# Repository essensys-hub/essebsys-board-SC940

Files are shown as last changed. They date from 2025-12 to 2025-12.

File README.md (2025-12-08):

# SC940 Board Project

Welcome to the **Essensys SC940 Board** project repository. This project contains the hardware design and firmware source code for the SC940 board.

## Documentation

Full documentation for this project is available and can be built using MkDocs.
It covers:
- **Hardware**: Schematics, PCB layouts, and manufacturing files.
- **Firmware**: Source code and programming guides.

### Viewing Documentation Locally
To view the documentation locally:

1. Install MkDocs and the Material theme:
   ```bash
   pip install mkdocs-material
   ```
2. Run the documentation server:
   ```bash
   mkdocs serve
   ```
3. Open your browser to `http://127.0.0.1:8000`.

## Project Structure

- `SC940D/`: Electronic design files (Altium Designer), including Schematics and PCB.
- `SC940D/Prog/`: Firmware source code and hex files.
- `docs/`: Documentation source files.
- `mkdocs.yml`: MkDocs configuration.

## License

This project is licensed under the MIT License - see the [LICENSE](LICENSE) file for details.

Copyright (c) 2025 Essensys

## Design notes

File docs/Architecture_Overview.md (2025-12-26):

# Vue d'ensemble de l'Architecture : Boîtier Essensys SC940D

## 1. Description Générale
Le **SC940D** est une unité centrale de contrôle ("Boîtier Pièce de Vie") conçue pour l'automatisation des bâtiments. Il agit comme une passerelle et un contrôleur d'actionneurs, gérant l'éclairage, les volets roulants et d'autres charges 230V via des relais embarqués.

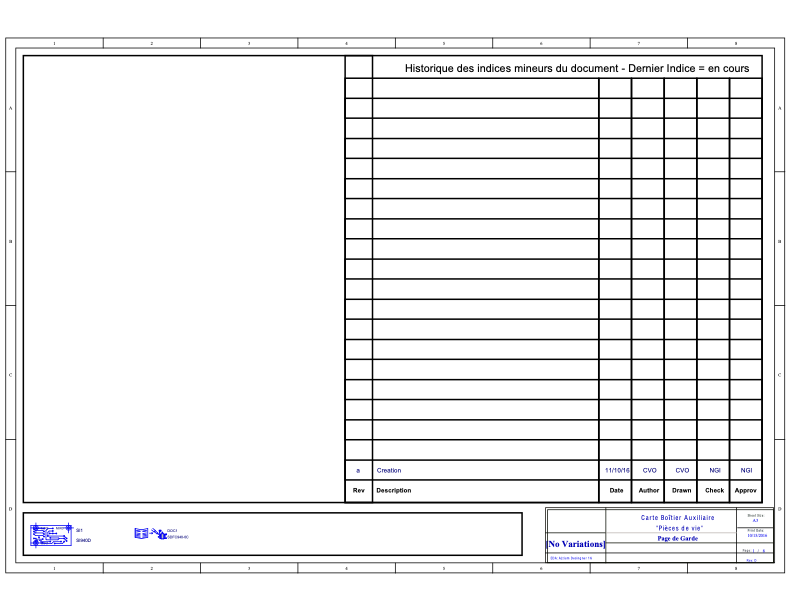
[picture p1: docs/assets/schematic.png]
SC940D Schematic

> [Télécharger le Schéma Complet (PDF)](assets/SC940D_Schematic.pdf)

## 2. Cœur de Traitement & Communication
### Microcontrôleur (MCU)
-   **Composant**: Microchip **PIC16F946** (MCU CMOS 8-bit).
-   **Boîtier**: 64-pin TQFP (`PIC16F946-I/PT`).
-   **Rôle**: Gère la logique locale, les signaux de contrôle des relais, et s'interface avec le module de communication. 
    -   *Note*: Le PIC16F946 possède un pilote LCD, mais il a probablement été choisi ici pour son grand nombre d'entrées/sorties (64 broches) ou pour des raisons d'historique composant.

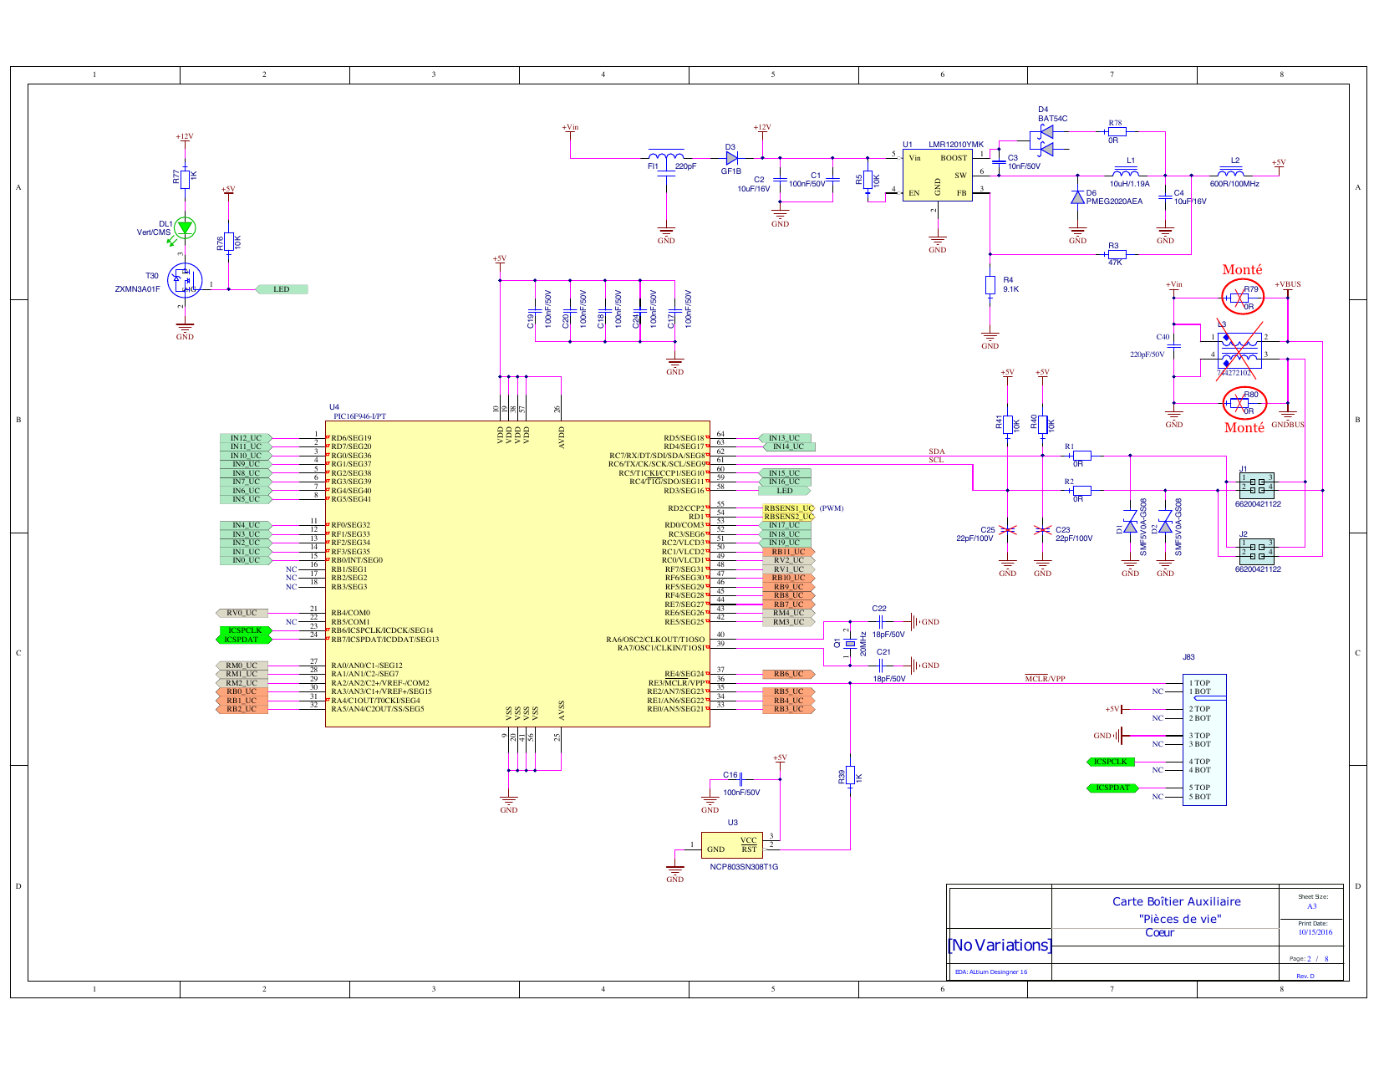
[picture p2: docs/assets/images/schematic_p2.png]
MCU Schematic Detail


### Module de Communication ("Cœur")
-   **Composant**: **SC943-0C** (Module Personnalisé).
-   **Empreinte**: `SI943C_REV_A`.
-   **Description**: Identifié comme une carte fille. Compte tenu de la nature du système, ce module gère probablement la communication RF (ex: LoRa, Zigbee, ou protocole propriétaire 868MHz).
-   **Interface**: Connecté au PCB principal via des connecteurs headers.

## 3. Chaîne d'Alimentation
-   **Entrée**: 12V DC (Nominale, fournie via connecteur).
-   **Régulateur Principal**: **LMR12010YMK** (Texas Instruments).
    -   Type: Convertisseur DC-DC Step-down (Buck).
    -   Boîtier: SOT-23-6.
    -   Efficacité: Haute efficacité (>85%) comparée aux régulateurs linéaires, idéal pour minimiser l'échauffement dans un boîtier fermé.
-   **Protection**:
    -   **VDR1, VR2, VR3**: Varistances (équivalent `VDR_S10K_275` pour la suppression des transitoires sur le secteur/entrées.
    -   **SMF5V0A**: Diodes TVS pour la protection ESD/Surtensions sur les lignes de signal basse tension.

## 4. Actionneurs & Interfaces
### Sorties Relais
La carte dispose d'une haute densité de relais pour la commutation de charges :
-   **Relais Haute Puissance**: Série **Finder 40.61** (16A, SPDT). Utilisés pour les charges principales.
-   **Relais Compacts**: Série **Finder 34.51** (6A, Ultra-mince). Utilisés pour les canaux de faible puissance ou à espace contraint.
-   **Pilotes**: **ZXMN3A01F** (MOSFETs Canal-N) utilisés pour piloter les bobines des relais.

### Connecteurs / Borniers
-   Utilisation intensive de borniers PCB verticaux **Phoenix Contact** (série `FFKDS`) pour le câblage terrain (Capteurs, Bus, Alimentation).
-   **HE10 / IDC**: Le connecteur `IDC2P54_26P` implique une interface par câble nappe 26 broches, possiblement pour la programmation, l'extension ou la connexion en façade.

## 5. Technologie PCB
-   **Couches**: Carte 4 Couches.
    -   **L1 (Top)**: Signaux & Composants.
    -   **L2 (G1)**: Plan de Masse Interne (GND) - Critique pour l'immunité au bruit.
    -   **L3 (G2)**: Plan d'Alimentation Interne (VCC) - Probablement divisé pour 12V / 3.3V / 5V.
    -   **L4 (Bottom)**: Signaux & composants secondaires.

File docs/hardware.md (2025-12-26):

# Conception Matérielle (Hardware Design)

La conception matérielle se trouve dans le répertoire `SC940D`.

## Schémas Électroniques

Le projet comprend plusieurs feuilles de schéma :
- **SC940D_Coeur.SchDoc**: Cœur logique (MCU).
- **SC940D_Borniers.SchDoc**: Connecteurs.
- **SC940D_ETOR1.SchDoc**, **SC940D_ETOR2.SchDoc**: Configurations des Entrées/Sorties.
- **SC940D_STORRB.SchDoc**, **SC940D_STORRM.SchDoc**: Composants de stockage/mémoire (Relais Bistables/Monostables).
- **SC940D_Variateurs.SchDoc**: Contrôle des variateurs.

## Routage PCB

Le routage du circuit imprimé est défini dans `SI940D.PcbDoc`.

## Documentation PDF

- [Schéma PDF (SC942-0B)](assets/pdfs/Schematic%20PDF_SC942-0B.pdf)
- [Plans d'Assemblage (SC942-0B)](assets/pdfs/Assembly%20Drawings_SC942-0B.pdf)
- [Datasheet Contrôleur (41250f)](assets/pdfs/41250f.pdf)

## Fabrication

Les fichiers de fabrication se trouvent dans `SC940D/Gerbers` et `SC940D/Assembly`.

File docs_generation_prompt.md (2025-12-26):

# Prompt Template pour la Documentation Automatisée de Modules

Utilisez ce prompt pour générer la structure de documentation pour un nouveau module (ex: SC941C). Copiez-collez ce texte dans votre assistant IA, en fournissant la liste des fichiers de votre dossier.

---

**Contexte**
Je souhaite publier la documentation technique d'un nouveau module hardware (ex: `SC9xx`) pour le projet Open Source **Essensys Atrium**.
Je dispose des fichiers bruts (Export Altium, PDFs, STEP, Gerbers) dans le répertoire courant.
Mon objectif est de créer un site statique **MkDocs** (thème Material) pour permettre aux utilisateurs de visualiser l'architecture et de télécharger les fichiers de fabrication.

**Fichiers disponibles (Input)**
*(Collez ici la liste de vos fichiers, par exemple :)*
- `Schematic PDF.pdf`
- `STEP_forSIxxxx.step`
- `Gerber for SIxxxx.zip`
- `SCxxxx` (Dossier sources)

**Tes instructions :**

1.  **Organisation des Fichiers (Assets)**
    *   Crée l'arborescence `docs/assets/` avec les sous-dossiers : `models/`, `manufacturing/`, `pdfs/`, `images/`.
    *   Renomme et déplace le fichier STEP vers `docs/assets/models/[NOM_MODULE].step`.
    *   Renomme et déplace le fichier ZIP des Gerbers vers `docs/assets/manufacturing/[NOM_MODULE]_Gerbers.zip`.
    *   Renomme et déplace les PDFs (Schéma, Assembly) vers `docs/assets/pdfs/`.
    *   Copie le PDF du schéma à la racine de `docs/assets/` sous le nom `[NOM_MODULE]_Schematic.pdf` pour un accès rapide.

2.  **Génération d'Images (Prévisualisation)**
    *   Si l'outil `pdftoppm` est disponible (ou via python), extrais les pages 2 (MCU) et 8 (Connecteurs) du PDF Schématique en PNG.
    *   Place-les dans `docs/assets/images/` (ex: `schematic_p2.png`).

3.  **Création du contenu Markdown (`docs/`)**
    *   `index.md`: Page d'accueil. Doit contenir :
        *   Une introduction "Open Source Hardware".
        *   La section "Aperçu du schéma" affichant les images générées (p2 et p8).
        *   Une liste des sections avec des émojis **Unicode** (🏛️ Architecture, 🔌 Hardware, 💾 Téléchargements).
    *   `downloads.md`: Page de téléchargements avec un tableau ou liste à cocher pour :
        *   📂 Schéma PDF
        *   📦 Modèle 3D (STEP)
        *   🏭 Fichiers de Fabrication (Gerbers ZIP)
    *   `hardware.md` et `architecture.md`: Crée les fichiers squelettes.

4.  **Documentation Firmware (`docs/firmware.md`)**
    *   Si un dossier de code source est présent (ex: `Prog/source`), analyse :
        *   `main.c`: Point d'entrée et gestion EEPROM.
        *   `hard.h` / `hard.c`: Mapping des Entrées/Sorties (Table de référence statique).
        *   `slavenode.c`: Protocole de communication.
    *   Crée `firmware.md` décrivant :
        *   L'environnement de build (Compilateur, MCU).
        *   La structure du projet.
        *   Le mapping mémoire (EEPROM).
        *   Le fonctionnement du mapping I/O (Hard Coded via macros).

5.  **Configuration (`mkdocs.yml`)**
    *   Génère le fichier `mkdocs.yml` complet configuré avec le thème `material` et la structure de navigation correspondante.
    *   Ajoute la configuration `markdown_extensions` pour activer `pymdownx.superfences` et le support **Mermaid**.

6.  **Pipeline CI/CD (`.github/workflows/publish.yml`)**
    *   Crée un workflow GitHub Actions pour déployer la documentation sur GitHub Pages.
    *   Utilise `actions/setup-python`, installe `mkdocs-material` et lance `mkdocs gh-deploy --force`.

7.  **Règles Importantes**
    *   Utilise des **émojis Unicode** directs (ex: 💾) et PAS de shortcodes (ex: `:floppy_disk:`) pour éviter les problèmes de rendu.
    *   Écris tout le contenu en **Français**.
    *   Reste factuel et technique.

---

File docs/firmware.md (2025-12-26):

# Documentation du Firmware

Le firmware de la carte **SC940D** est développé en C pour le microcontrôleur **Microchip PIC16F946**.

## Environnement de Développement
- **Compilateur**: Hi-Tech C pour PIC10/12/16.
- **IDE**: MPLAB X (Fichier projet `essensys_ba.X`).
- **MCU**: PIC16F946.
- **Horloge**: Oscillateur High Speed (HS).
- **Watchdog**: Désactivé au démarrage (`WDTDIS`).

## Structure du Projet
Le code source se trouve dans `SC940D/Prog/code_ba (fichiers sources 1.7)/source/`.

| Fichier | Description |
| :--- | :--- |
| `main.c` | Point d'entrée, initialisation et gestion EEPROM. |
| `hard.c/h` | Couche d'Abstraction Matérielle (HAL). Définition des broches et I/O de bas niveau. |
| `gestionentrees.c` | Traitement des signaux d'entrée et anti-rebond. |
| `gestionsorties.c` | Logique de commande des sorties (Relais). |
| `variateur.c` | Algorithmes de contrôle des gradateurs ("Variateurs"). |
| `traitement.c` | Logique applicative principale et machine à états. |
| `slavenode.c` | Implémentation du protocole de communication (Bus I2C). |

## Cartographie Mémoire (EEPROM)
L'EEPROM est utilisée pour stocker la configuration persistante et l'état.

| Adresse | Description |
| :--- | :--- |
| `0x000D` | Version du Mapping EEPROM. |
| `0x000E-0F` | Vérification d'initialisation (`0xAA55`). |
| `0x0010-11` | État des Relais (LSB/MSB). |
| `0x0012-29` | Configuration Variateurs (Niveau actuel, Niveau sauvegardé, Mode). |
| `0x002A-31` | Temps d'action des Volets. |
| `0x0032-42` | Temps d'extinction des lampes. |

## Fonctionnalités Clés
1.  **Persistance d'État**: Les états des relais et niveaux des variateurs sont sauvegardés en EEPROM pour restaurer l'état après une coupure de courant.
2.  **Gestion des Entrées**: Traitement direct des entrées numériques avec anti-rebond.
3.  **Contrôle de Charge**:
    - **Relais**: Contrôle simple On/Off.
    - **Variateurs**: Contrôle de phase ou PWM pour l'éclairage.
    - **Volets**: Contrôle temporisé pour l'ouverture/fermeture des stores.
4.  **Communication**: Utilise un protocole "Nœud Esclave" propriétaire, via I2C pour communiquer avec le contrôleur central (`SC944D`).

## Adressage et Mapping des Entrées (Logique vs Physique)

Le firmware utilise des tables de correspondance statiques (définies dans `gestionentrees.c`) pour associer les **Entrées Logiques** (index utilisé par le protocole) aux **Broches Physiques** du microcontrôleur (`ENTREE0` à `ENTREE21`).

⚠️ **Attention** : Vous ne pouvez pas utiliser n'importe quelle broche d'entrée pour n'importe quelle fonction. L'assignation est fixée par la configuration logicielle de la carte (définie à la compilation par des `#define`).

Voici les mappings extraits du code source :

### Configuration `TYPE_CHAMBRES`
| Type Logique | Index Logique | Mapped sur Physique | Pin Physique (Est.) |
| :--- | :--- | :--- | :--- |
| **TOR** | 0 | `ENTREE0` | RB0 |
| **TOR** | 1 | `ENTREE2` | RF4 |
| **TOR** | 2 | `ENTREE3` | RF3 |
| **TOR** | 3 | `ENTREE9` | RG2 |
| **TOR** | 4 | `ENTREE10` | RG1 |
| **TOR** | 5 | `ENTREE14` | RD4 |
| **TOR** | 6 | `ENTREE18` | RC0 |
| **Variateur** | 0 | `ENTREE1` | RF5 |
| **Variateur** | 1 | `ENTREE8` | RG3 |
| **Variateur** | 2 | `ENTREE13` | RD5 |
| **Variateur** | 3 | `ENTREE17` | RD0 |
| **Volet** | 0 | `ENTREE4` | RF1 |
| **Volet** | ... | ... | ... |

*(Note : Les correspondances Pin/Port exactes dépendent de `hard.h`)*

Ce mécanisme confirme que même si les entrées `IN0` à `IN12` sont physiquement présentes sur le connecteur, elles ne seront "vues" par le firmware que si elles sont déclarées dans ces tables de mapping.

## Analyse de la Communication Maître-Esclave

La carte **SC940D** agit comme un module d'Entrée/Sortie esclave générique, piloté par un concentrateur maître (ex: **944D**).

### Protocole
- **Couche Physique**: I2C (basé sur le nommage `slavenode.c` et l'usage de `SSPBUF`).
- **Mécanisme**:
    1.  **Interruption**: `SSP_Handler` reçoit les octets bruts dans `RXBuffer`.
    2.  **Validation**: Un Checksum est calculé (`us_CalculerCRCSurTrame`). Si valide, les données sont copiées dans `CmdBuf`.
    3.  **Exécution**: La boucle principale appelle `vd_Traitement_I2C` qui traite `CmdBuf`.

### Diagramme de Flux (Logique Firmware)

```mermaid
graph TD
    subgraph Interrupt[Interruption - ISR]
        ISR(SSP_Handler) --> Recv[Réception Octet]
        Recv --> Buffer{"Buffer Plein ?"}
        Buffer -- Non --> Store[Stockage RXBuffer]
        Buffer -- Oui --> Checksum[Vérif. Checksum]
        Checksum -- Valide --> Copy[Copie vers CmdBuf]
        Checksum -- Invalide --> Error[Flag Erreur]
    end

    subgraph MainLoop[Boucle Principale]
        Start((Départ)) --> Init[Initialisation]
        Init --> Loop{"While(1)"}
        Loop --> Task1[vd_Traitement_I2C]
        Task1 --> CmdCheck{"CmdBuf[0] != 0?"}
        
        CmdCheck -- Oui --> Switch[Switch Commande]
        Switch --> C1[C_FORCAGE_SORTIES]
        Switch --> C2[C_CONF_SORTIES]
        Switch --> C3[C_TPS_EXTINCTION]
        
        C1 --> Action1[MàJ Relais/Variateurs]
        C2 --> Action2[MàJ Config & EEPROM]
        C3 --> Action3[MàJ Timers & EEPROM]
        
        Action1 --> Reset["CmdBuf[0] = 0"]
        Action2 --> Reset
        Action3 --> Reset
        
        Reset --> Loop
        CmdCheck -- Non --> Loop
    end
```

### Commandes du Protocole

| ID Commande | Nom | Description |
| :--- | :--- | :--- |
| `0x01` | `C_FORCAGE_SORTIES` | Force l'état des relais, variateurs ou volets. |
| `0x02` | `C_CONF_SORTIES` | Configure le mode variateur (On/Off ou Gradation). |
| `0x03` | `C_TPS_EXTINCTION` | Définit le temps d'extinction auto pour les lampes. |
| `0x04` | `C_TPS_ACTION` | Définit le temps de mouvement pour les volets. |
| `0x05` | `C_ACTIONS` | Déclenche des actions globales (ex: Sauvegarde État). |

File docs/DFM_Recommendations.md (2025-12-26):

# Recommandations DFM (Design for Manufacturing) & Optimisation

## 1. Empilement PCB & Fabrication
-   **Empilement Actuel**: 4 Couches (Sig/GND/PWR/Sig).
-   **Recommandation**: Assurez-vous que les profils d'impédance contrôlée sont spécifiés si le module de communication (`SC943`) utilise des lignes haute vitesse ou des antennes externes routées sur la carte principale.
-   **Tailles de Perçage**: Vérifiez que les mises à jour de tolérance de la "Release 16.0" sont compatibles avec le fabricant de PCB choisi (capacités standard vs avancées).

## 2. Testabilité (DFT)
-   **Points de Test**: La conception inclut `MIR1`, `MIR2`, `MIR3` (Mires fiduciales) mais manque de points de test explicitement étiquetés pour les signaux critiques (ex: `TP_3V3`, `TP_GND`, `TP_MCLR`).
-   **Recommandation**: Ajouter des pastilles de test dédiées (diamètre 1mm) pour :
    -   Rails de Tension (12V, 5V, 3.3V).
    -   Bus de Communication (Lignes TX/RX vers le module).
    -   Broches ICSP / Programmation pour le PIC16F946 (sauf si géré par le connecteur HE10).

## 3. Assemblage & Gestion Thermique
-   **Densité de Relais**: La carte embarque environ 17 relais.
    -   **Risque**: Échauffement localisé important si plusieurs relais adjacents (`K1`-`K3`, `K4`-`K9`) sont actifs simultanément.
    -   **Atténuation**: Assurez-vous que le boîtier dispose de fentes de ventilation au-dessus de la banque de relais. Vérifiez la largeur des pistes PCB pour le contact "Commun" des relais (~16A nécessite une largeur de cuivre significative ou des plans de masse).
-   **Dégagement des Composants**: Les borniers verticaux (`Phoenix Contact FFKDS`) sont hauts. Assurez-vous qu'ils n'interfèrent pas avec le couvercle du boîtier ou le placement de la carte fille (`SC943`).

## 4. Cycle de Vie des Composants
-   **PIC16F946**: C'est un produit ancien et mature. Vérifiez la disponibilité à long terme ou envisagez de migrer vers une série PIC16F1xxx ou PIC18F plus récente pour une meilleure densité de code et une consommation réduite.
-   **LMR12010**: Actif et bonne disponibilité.
-   **Relais**: Les séries Finder 40/34 sont des standards de l'industrie avec une excellente disponibilité.

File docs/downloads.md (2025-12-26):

# Téléchargements (Downloads)

Accéder aux ressources techniques pour imprimer les pièces mécaniques ou fabriquer la carte électronique.

## Schémas Électroniques
Le schéma complet de la carte SC940D au format PDF pour consultation et réparation.

- [x] 📂 **Schéma SC940D** (PDF) -> [Télécharger](assets/SC940D_Schematic.pdf)

## Modélisation 3D
Fichier STEP de la carte complète pour l'intégration mécanique.

- [x] 📦 **Modèle 3D SC940D** (STEP) -> [Télécharger](assets/models/SC940D.step)

## Fabrication (Gerbers)
Dossier de fabrication complet (Gerber X2) pour la production du PCB.

- [x] 🏭 **Fichiers de Fabrication SC940D** (ZIP) -> [Télécharger](assets/manufacturing/SC940D_Gerbers.zip)

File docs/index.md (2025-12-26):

# Documentation SC940D

Bienvenue sur la documentation officielle de la carte **SC940D**, composant "Boitier Pièce de Vie" de la solution domotique Essensys Atrium.

## À propos du projet
La carte SC940D est une unité de contrôle centrale conçue pour l'automatisation du bâtiment. Elle agit comme une passerelle et un contrôleur d'actionneurs, gérant l'éclairage, les stores et d'autres charges CA via des relais embarqués.

Ce projet est Open Source Hardware. Vous trouverez ici toutes les informations nécessaires pour comprendre, fabriquer, réparer et intégrer cette carte.

## Aperçu du schéma
Pour vous donner un aperçu rapide, voici les éléments clés du circuit (Microcontrôleur et Connecteurs) :

Microcontrôleur (Page 2)
*Figure 1: Schéma du cœur numérique (Microcontrôleur)*

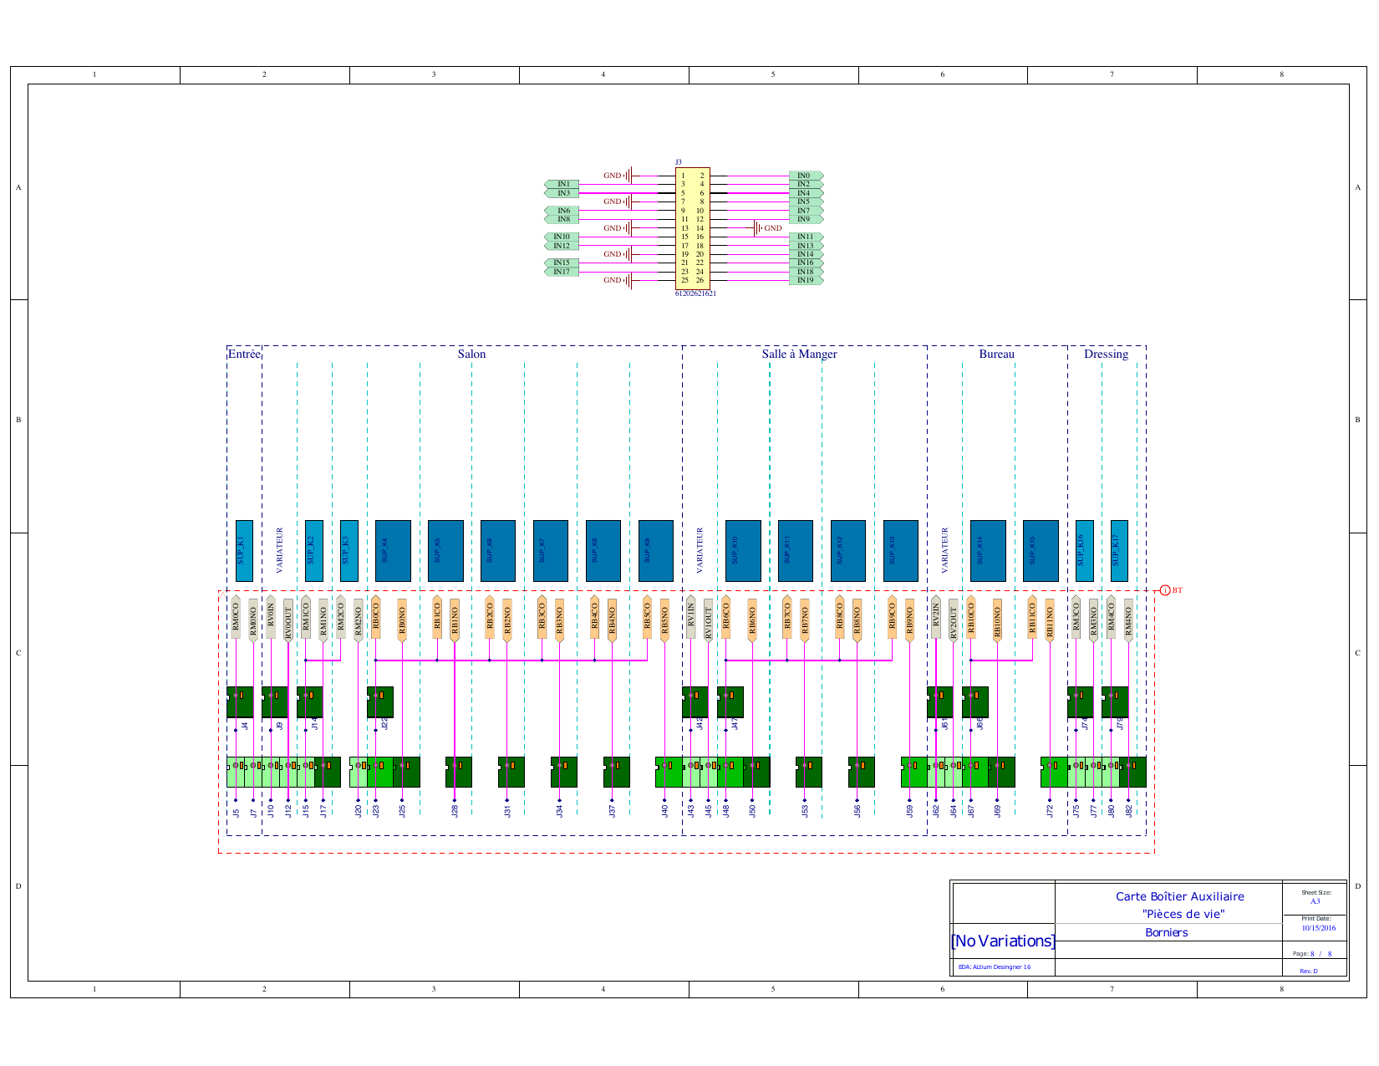
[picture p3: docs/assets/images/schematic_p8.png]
Connecteurs (Page 8)

*Figure 2: Schéma des connecteurs et interfaces*

## Contenu de la documentation

### 🏛️ Architecture
Comprenez le fonctionnement interne de la carte, son microcontrôleur PIC16F946 et son étage de puissance.
[➡️ Architecture Overview](Architecture_Overview.md)

### 🔌 Hardware
Détails techniques, recommandations de fabrication (DFM) et gestion de l'alimentation.
[➡️ Spécifications Hardware](hardware.md)

### 💾 Téléchargements
Accédez aux fichiers sources pour la production : schémas PDF, modèles 3D STEP et fichiers de fabrication Gerber.
[➡️ Espace de téléchargement](downloads.md)

## Structure du dépôt
Le code source et les fichiers de conception sont organisés comme suit :
- **SC940D/** : Dossier principal du projet (Hardware Altium).
    - **Schematics** : Schémas électroniques.
    - **PCB Layout** : Routage de la carte.
   - **Gerbers** : Fichiers de fabrication.

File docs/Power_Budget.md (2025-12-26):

# Estimation du Budget de Puissance : SC940D

> [!WARNING]
> Ce budget est une estimation théorique basée sur les fiches techniques des composants et des valeurs typiques. Une vérification réelle sur le matériel est requise.

## 1. États du Système
Nous définissons deux états de puissance principaux pour l'analyse :
1.  **Repos / Veille (Idle)**: MCU en marche, Module communication en réception/sommeil, aucun relais actif.
2.  **Transmission Max**: Module communication en émission (TX), MCU actif.
3.  **Activation Complète**: Tous les relais activés (Pire Cas).

## 2. Analyse de Consommation par Composant

### A. Cœur Logique (Rail 3.3V / 5V)
| Composant | État | Courant (Est.) | Puissance (Est.) |
| :--- | :--- | :--- | :--- |
| **PIC16F946** | Marche (4MHz) | ~2 mA | 10 mW |
| **PIC16F946** | Sommeil | < 1 µA | ~0 mW |
| **SC943 (Module)** | Repos/RX | ~10-20 mA | ~50-100 mW |
| **SC943 (Module)** | TX (RF Haut) | ~100-150 mA | ~500 mW |
| **Protection/Fuite** | Veille | < 100 µA | < 1 mW |

### B. Actionneurs (Rail 12V)
*Note : Les bobines des relais sont les principaux consommateurs d'énergie.*

| Composant | Quantité | Courant Unitaire (12V) | Puiss. Unitaire | Puiss. Max Totale |
| :--- | :--- | :--- | :--- | :--- |
| **Finder 40.61** | ~12 | ~40 mA (0.5W) | 0.5 W | 6.0 W |
| **Finder 34.51** | ~5 | ~15 mA (0.17W) | 0.17 W | 0.85 W |

## 3. Estimation Totale de Puissance (Entrée 12V)

### Scénario 1 : Veille (Aucun Relais)
-   **Charge Logique**: ~20mA @ 5V (via Buck)
-   **Efficacité Buck**: ~85%
-   **Courant Entrée (12V)**: ~1-10 mA.
-   **Puissance Totale**: **< 0.2 W**.

### Scénario 2 : Opération Typique (2 Relais Actifs + RX)
-   **Relays**: 2x 40.61 = 1 W.
-   **Logique**: 0.1 W.
-   **Puissance Totale**: **~1.1 W**.

### Scénario 3 : Pire Cas (Tous Relais ON + TX)
-   **Relais**: 6.85 W.
-   **Logique (TX)**: 0.5 W / 0.85 (Eff) ≈ 0.6 W.
-   **Puissance Totale**: **~7.5 W**.

## 4. Recommandations
1.  **Dimensionnement PSU**: L'alimentation 12V amont doit être dimensionnée pour au moins **10W (ou ~1A)** pour gérer le pire cas et le courant d'appel.
2.  **Thermique**: 7.5W représente une chaleur significative. Assurez-vous que le boîtier permet une convection passive si l'état "Tout ON" est possible.
3.  **Optimisation Firmware**: Implémentez un "démarrage progressif" ou une activation séquencée des relais pour éviter que les pics de courant (appel) ne saturent le rail d'alimentation simultanément.

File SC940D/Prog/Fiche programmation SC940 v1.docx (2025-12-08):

FICHE DE PROGRAMMATION

Microcontrôleur SC940

Microcontrôleur : PIC16F946-I/PT

Logiciel de programmation : MPLAB IPE

Outils de programmation : PICKit 3 + Interface de programmation BA

Procédure :

- Lancer MPLAB IPE.
- Brancher les outils de programmation.
- Alimenter la carte

Remarque : l'outil peut être raccordé à chaud carte déjà sous tension.

- Aller dans le menu "Settings -> Advanced mode".

Entrer le mot de passe "microchip".

- Aller dans l'onglet de gauche "Operate" :
- Dans l'onglet de gauche "Operate", cliquer sur le bouton "Connect".

Le message suivant apparait :

MESSAGE A COLLER

- Cliquez sur "OK" (alim en 5V donc OK).
- Choisir le microcontrôleur dans le menu déroulant "Device".
- Cliquer sur "Browse" de la ligne "Source".

Choisir le fichier .hex à programmer.

Vérifier que le checksum dans la case "Checksum" correspond bien à celui entre parenthèse à la fin du nom du fichier.

Attention : si le microcontrôleur choisit n'est pas le bon, le checksum ne correspondra pas.

Cliquer sur OK.

- Cliquez sur le bouton "Program".

Attention : un verify est déjà inclus dans la programmation.

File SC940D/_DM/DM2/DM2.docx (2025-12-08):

DM2

L'ajout de la self de mode commun Würth 744272102 pose des problèmes de référence 0V et la communication n'est plus reconnue.

On supprime la self Würth 744272102 L3 et la capa 220pF C40 qui n'a plus de sens non plus.

On soude à la place les 2 résistances 0 Ohm 0805, R79 et R80 prévue pour shunter la self.

Sur la génération actuelle :

Correction à la main sur le schéma.

Correction à la main en nomenclature.

Sur la prochaine génération :

A voir.

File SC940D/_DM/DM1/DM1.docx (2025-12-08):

DM1

Le niveau 0 sur les pattes de uC IN19_UC et IN20_UC sont trop haut (> 0,6V assurant un niveau logique 0). C'était visiblement le cas sur la génération précédente car corrigé par des changements de valeurs de résistances. Mais celà a été non tracé, donc non prix en compte lors de la dernière reprise.

On remplace R71 par 2k2 à la place de la 22k actuelle.

=> IN19_UC = 127mV au 0 logique.

Sur la génération actuelle :

Correction à la main sur le schéma.

Correction à la main en nomenclature.

Sur la prochaine génération :

Correction du chéma en CAO.

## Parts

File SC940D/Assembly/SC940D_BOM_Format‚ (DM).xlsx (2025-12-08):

Description | Fabricant | Ref Fab | Value | Quantity | Designator | Footprint
Circuit imprimé | Valentinéa | SI940D | - | 1 | SI1 | CIRCUIT_IMPRIME_SI_STD
Carte gradateur | Valentinéa | SC943D | - | 3 | U2, U5, U7 | SI943C_REV_A
Résistance CMS 0805, 0.125W, 1%, 100ppm, 150V | Vishay | CRCW08050000Z0EA | 0R | 5 | R1, R2, R78, R79, R80 | 0805_ReflowSoldering_RES
Résistance CMS 0805, 0.125W, 1%, 100ppm, 150V | Vishay | CRCW08051K00FKEA | 1K | 2 | R39, R77 | 0805_ReflowSoldering_RES
Résistance CMS 0805, 0.125W, 1%, 100ppm, 150V | Vishay | CRCW08052K20FKEA | 2.2K | 1 | R71 | 0805_ReflowSoldering_RES
Résistance CMS 0805, 0.125W, 1%, 100ppm, 150V | Vishay | CRCW08056K80FKEA | 6.8K | 20 | R11, R14, R17, R20, R23, R26, R29, R32, R35, R38, R43, R48, R51, R54, R57, R60, R63, R66, R69, R72 | 0805_ReflowSoldering_RES
Résistance CMS 0805, 0.125W, 1%, 100ppm, 150V | Vishay | CRCW08059K10FKEA | 9.1K | 1 | R4 | 0805_ReflowSoldering_RES
Résistance CMS 0805, 0.125W, 1%, 100ppm, 150V | Vishay | CRCW080510K0FKEA | 10K | 31 | R5, R6, R7, R8, R9, R12, R16, R18, R21, R24, R27, R31, R34, R36, R40, R41, R44, R45, R46, R49, R52, R55, R58, R61, R64, R67, R70, R73, R74, R75, R76 | 0805_ReflowSoldering_RES
Résistance CMS 0805, 0.125W, 1%, 100ppm, 150V | Vishay | CRCW080522K0FKEA | 22K | 19 | R10, R13, R15, R19, R22, R25, R28, R30, R33, R37, R42, R47, R50, R53, R56, R59, R62, R65, R68 | 0805_ReflowSoldering_RES
Résistance CMS 0805, 0.125W, 1%, 100ppm, 150V | Vishay | CRCW080547K0FKEA | 47K | 1 | R3 | 0805_ReflowSoldering_RES
Condensateur céramique, NPO, 5%, CMS 0603 | Kemet | C0603C180J5GAC | 18pF/50V | 2 | C21, C22 | 0603_ReflowSoldering_CAP
Condensateur céramique, X7R, 10%, CMS 0603 | Kemet | C0603C103K5RAC | 10nF/50V | 1 | C3 | 0603_ReflowSoldering_CAP
Condensateur céramique, X7R, 10%, CMS 0805 | Kemet | C0805C104K5RAC | 100nF/50V | 31 | C1, C5, C6, C7, C8, C9, C10, C11, C12, C13, C14, C15, C16, C17, C18, C19, C20, C24, C26, C27, C28, C29, C30, C31, C32, C33, C34, C35, C36, C37, C38 | 0805_ReflowSoldering_CAP
Condensateur céramique, X5R, 10%, CMS 0805 | Kemet | C0805C106K4PAC | 10uF/16V | 3 | C2, C4, C39 | 0805_ReflowSoldering_CAP
Inductance bobinée CMS, 10uH +/- 10%, I=1.19A, Rdc=0.095R, SRF=40MHz, -40/+85°C | Wurth Elektronik | 744043100 | 10uH/1,19A | 1 | L1 | SELF_WE-TPC_4.8x4.78_(type4828)
Ferrite multicouches CMS, imp=600R@100MHz, +/-25%, Rdc=100mR, I=2A | Wurth Elektronik | 74279218 | 600R/100MHz | 1 | L2 | 1206_ReflowSoldering_FERRITE
Filtre EMI selfique-capacitif, -20/+50%, 25Vcc/6A, -40/+85°C | Murata | NFE31PT221D1E9L | 220pF | 1 | FI1 | NFE31P
Quartz CMS série HCM49 (équiv HC49/US), -10/+60°C, +/-30ppm, 18pF | Citizen | HCM49 20.000MABJ-UT | 20MHz | 1 | Q1 | QUARTZ_HC49_11.5X5_CMS
Diode de Redressement, Vrrm=100V, If=1A, Vf=1.1V, CMS | Fairchild | GF1B | - | 1 | D3 | DO214BA-P
Diode Schottky double, BAT54 cathode com, Vrrm=30V, If=300mA, Vf=0.4Vmax, CMS | NXP | BAT54C | - | 18 | D4, D7, D8, D9, D11, D15, D19, D23, D24, D25, D27, D29, D31, D34, D37, D39, D42, D43 | SOT23_3L_ReflowSoldering
Diode Schottky, Vrrm=20V, If=2A, Vf=450mV, CMS | NXP | PMEG2020AEA | - | 1 | D6 | SOD323_ReflowSoldering
Diode Transil/TVS unidirectionnelle (A), 200W, 5V, CMS | Vishay | SMF5V0A | - | 22 | D1, D2, D10, D12, D13, D14, D16, D17, D18, D20, D21, D22, D26, D28, D30, D32, D33, D35, D36, D38, D40, D41 | DO219AB-SMF-P_ReflowSoldering
Varistance disque 275Vac, 350Vdc, 33J, Vbreak=430V@1mA, Vclamp=710V@10A, Ipeak=1200A | Wurth Elektronik | 820572711 | 710V | 3 | VR1, VR2, VR3 | VDR_Serie_820_d7_h13_e5mm
~~LED vert, Vf 2V@20mA, 40mCd, vue 140°, CMS 0805~~ LED vert, Vf 2,2V@20mA, 12mCd, vue 120°, CMS 0805 | ~~Wurth Elektronik~~ Kingbright | ~~150080VS75000~~ KP2012-SGC | - | 1 | DL1 | LED_0805_KPx_Green
Transistor MOSN logique, Vdss=30V, Id=2A, Rdson=0.12R, CMS | Zetex | ZXMN3A01F | - | 30 | T1, T2, T3, T4, T5, T6, T7, T8, T9, T10, T11, T12, T13, T14, T15, T16, T17, T18, T19, T20, T21, T22, T23, T24, T25, T26, T27, T28, T29, T30 | SOT23_3L_ReflowSoldering
Régulateur ajustable step down, 0.8~20V, 1A, Vin=3~20V, -40/+125°C, CMS | National Semiconductor | LMR12010YMK | - | 1 | U1 | SOT23_6L
Superviseur de Reset pour microcontrolleur 3.08V -Pin SOT-23, CMS | ON | NCP803SN308T1G | - | 1 | U3 | SOT23_3L_ReflowSoldering
Dual High-Speed 1.5A MOSFET Driver, CMS | Micrel | MIC4426YM | - | 1 | U6 | SOIC_08_E1,27_L150_ReflowSoldering
Microcontrôleur 8bit | Microchip | PIC16F946-I/PT | - | 1 | U4 | QFP_064_E0,50_10X10MM
Relais 1RT, 12Vdc, série 34.51, Rc=1940R, Sw:250Vac/6A, Ron=? (AgSnO2) | Finder | 34.51.7.012.4010 | - | 5 | K1, K2, K3, K16, K17 | RELAY_FINDER_34.51_+SUPPORT_93
Relais 1RT, 12Vdc, série 40.61.6 (bistable), Rc=900R, Sw:250Vac/16A, Ron=? (AgSnO2) | Finder | 40.61.6.012.4000 | - | 12 | K4, K5, K6, K7, K8, K9, K10, K11, K12, K13, K14, K15 | RELAY_FINDER_40.61_+SUPPORT_95
Suppor série 93 pour relais Finder séries 34, 250V/6A, Bleu | Finder | 93.11 | - | 5 | SUP_K1, SUP_K2, SUP_K3, SUP_K16, SUP_K17 | RELAY-SUPPORT_FINDER_SERIE93
Suppor série 95 pour relais Finder séries 40, 250V/10A, Bleu, sans Etrier | Finder | 95.15.2 SMA | - | 12 | SUP_K4, SUP_K5, SUP_K6, SUP_K7, SUP_K8, SUP_K9, SUP_K10, SUP_K11, SUP_K12, SUP_K13, SUP_K14, SUP_K15 | RELAY-SUPPORT_FINDER_SERIE95
Bornier à connexion par ressorts/déconnexion par levier, série FFKDS/V2, e5.08, 1x1pts, droit, juxtaposable, 320V/15A, AWG22~16, Vert/Orange | Phoenix Contact | 1790348 | - | 13 | J5, J7, J10, J12, J15, J20, J43, J45, J62, J64, J75, J77, J80 | BRESS_FFKDS/V2-5,08_P1.3
Bornier à connexion par ressorts/déconnexion par levier, série FFKDSA/V2, e7.62, 1x1pts, droit, juxtaposable, 500V/17.5A, AWG22~16, Vert/Orange | Phoenix Contact | 1790377 | - | 6 | J23, J40, J48, J59, J67, J72 | BRESS_FFKDSA/V2-7,62_P1.3
Bornier à connexion par ressorts/déconnexion par levier, série FFKDSA1/V2, e7.62, 1x1pts, droit, terminaison, 500V/17.5A, AWG22~16, Vert/Orange | Phoenix Contact | 1790487 | - | 21 | J4, J9, J14, J17, J22, J25, J28, J31, J34, J37, J42, J47, J50, J53, J56, J61, J66, J69, J74, J79, J82 | BRESS_FFKDSA1/V2-7,62_P1.3
26 Positions Header, Shrouded Connector 0.100" (2.54mm) Through Hole Gold | Wurth Elektronik | 61202621621 | - | 1 | J3 | IDC2P54_26P
Embase type Micro Mate-n-Lok, e3mm, 4pts, droit, cont. étamés 20mR, 250V/5A, Iso 1500V, -40/+105°C | Wurth Elektronik | 66200421122 | - | 2 | J1, J2 | MICRO-MATE-N-LOK_WURTH+TYCO_2X02_D

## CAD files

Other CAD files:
SC940D/3D/SC940D/C6_1.sldasm
SC940D/3D/SC940D/L1_1.sldasm
SC940D/3D/SC940D/J75.sldasm
SC940D/3D/SC940D/R35.sldasm
SC940D/3D/SC940D/R17_1.sldasm
SC940D/3D/SC940D/K13.sldasm
SC940D/3D/SC940D/J47.sldasm
SC940D/3D/SC940D/T17.sldasm
SC940D/3D/SC940D/R9_1.sldasm
SC940D/3D/SC940D/R54.sldasm
SC940D/3D/SC940D/D4.sldasm
SC940D/3D/SC940D/T28.sldasm
SC940D/3D/SC940D/D29.sldasm
SC940D/3D/SC940D/C8.sldasm
SC940D/3D/SC940D/STEP-744272102-rev1_RGB8421504.sldasm
SC940D/3D/SC940D/R1.sldasm
SC940D/3D/SC940D/D36.sldasm
SC940D/3D/SC940D/T23.sldasm
SC940D/3D/SC940D/1151710376.sldasm
SC940D/3D/SC940D/1151710512.sldasm
SC940D/3D/SC940D/1151724792.sldasm
SC940D/3D/SC940D/1151724928.sldasm
SC940D/3D/SC940D/1151725064.sldasm
SC940D/3D/SC940D/1790348.sldasm
SC940D/3D/SC940D/1790377.sldasm
SC940D/3D/SC940D/1790487.sldasm
SC940D/3D/SC940D/61202621621.sldprt
SC940D/3D/SC940D/6120xx21621_PIN.sldprt
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

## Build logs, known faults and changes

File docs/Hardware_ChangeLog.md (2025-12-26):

# Historique des Modifications Matérielles (SC940D)

Ce document retrace l'historique des révisions du PCB SC940D tel qu'extrait des fichiers de conception.

| Version | Description | Criticité |
| :--- | :--- | :--- |
| **Release 16.0** | **Version Actuelle**. Ajout des valeurs de tolérance pour la taille des trous de Pads/Vias. | **Caution** |
| **Release 15.1** | Support du texte PCB multi-lignes ajouté. Note : vérifier le rendu du texte sur les anciens logiciels CAM. | Caution |
| **Release 15.0** | Support des masques de soudure séparés pour le dessus et le dessous des pads ajouté. | Caution |

## Modifications Anciennes / Non Vérifiées
> [!NOTE]
> Les anciennes révisions (Pré-15.0) ne sont pas détaillées dans l'export actuel. Veuillez vous référer aux archives dans `SC940D/_Archives` si disponibles.

## Problèmes Connus (Design Actuel)
-   **Manque de Documentation**: Le module "Cœur" (`SC943`) manque de schéma détaillé dans l'arborescence principale du projet.
-   **Saut de Désignateurs**: Les désignateurs des composants sautent des valeurs (ex: Relais K1-K17, puis un trou ?), typique des conceptions ayant évolué.

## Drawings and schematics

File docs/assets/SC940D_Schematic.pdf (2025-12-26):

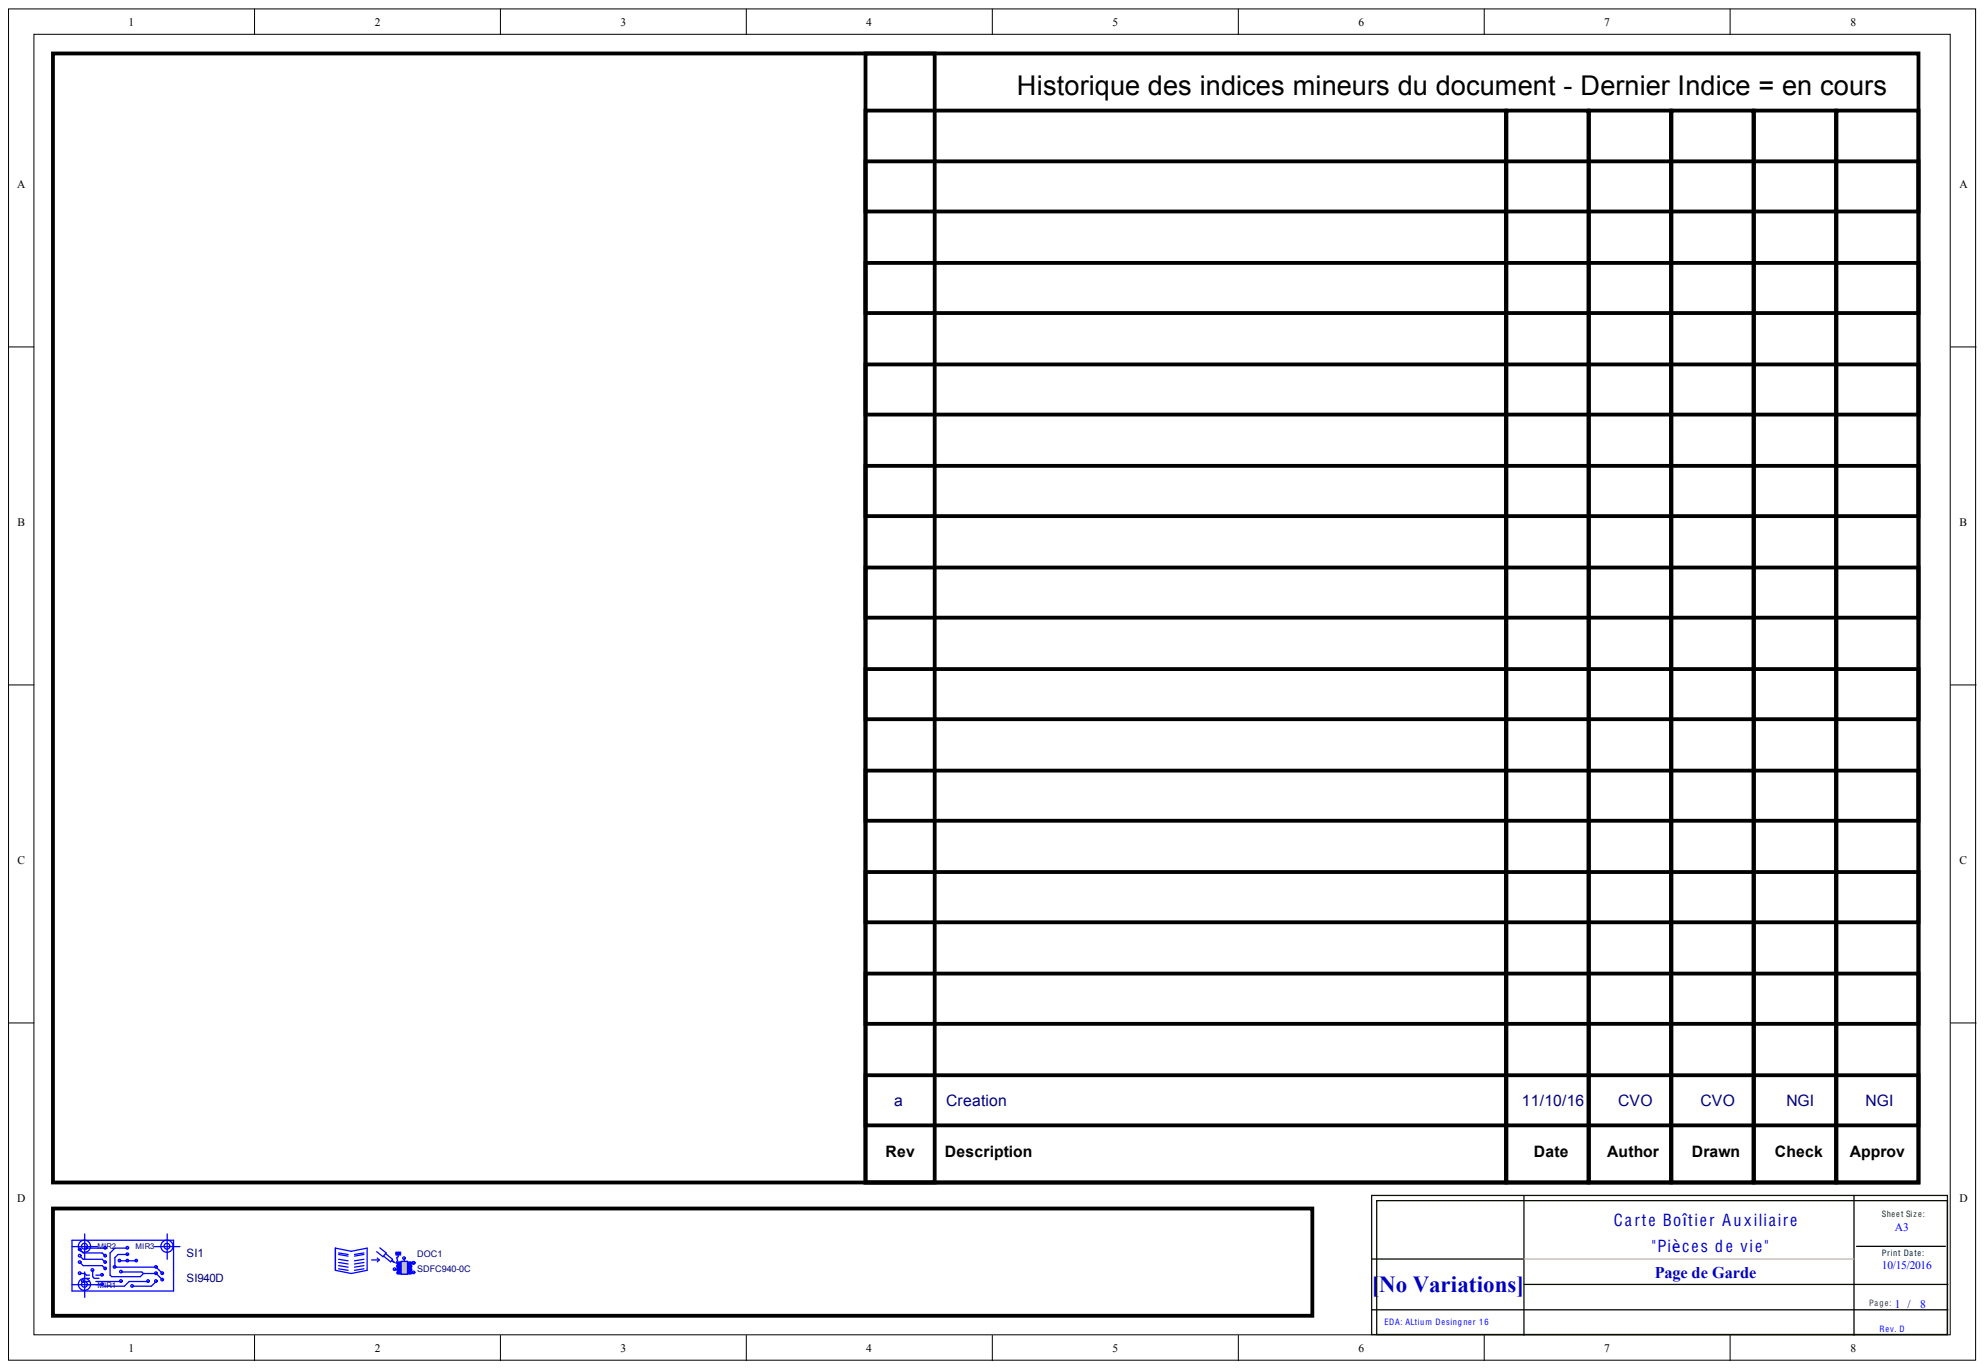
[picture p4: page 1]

Historique des indices mineurs du document - Dernier Indice = en cours

a | Creation | 11/10/16 | CVO | CVO | NGI | NGI

Rev | Description | Date | Author | Drawn | Check | Approv

[No Variations] | Page de Garde

EDA: ALtium Desing ner 1 6 | | Rev. D

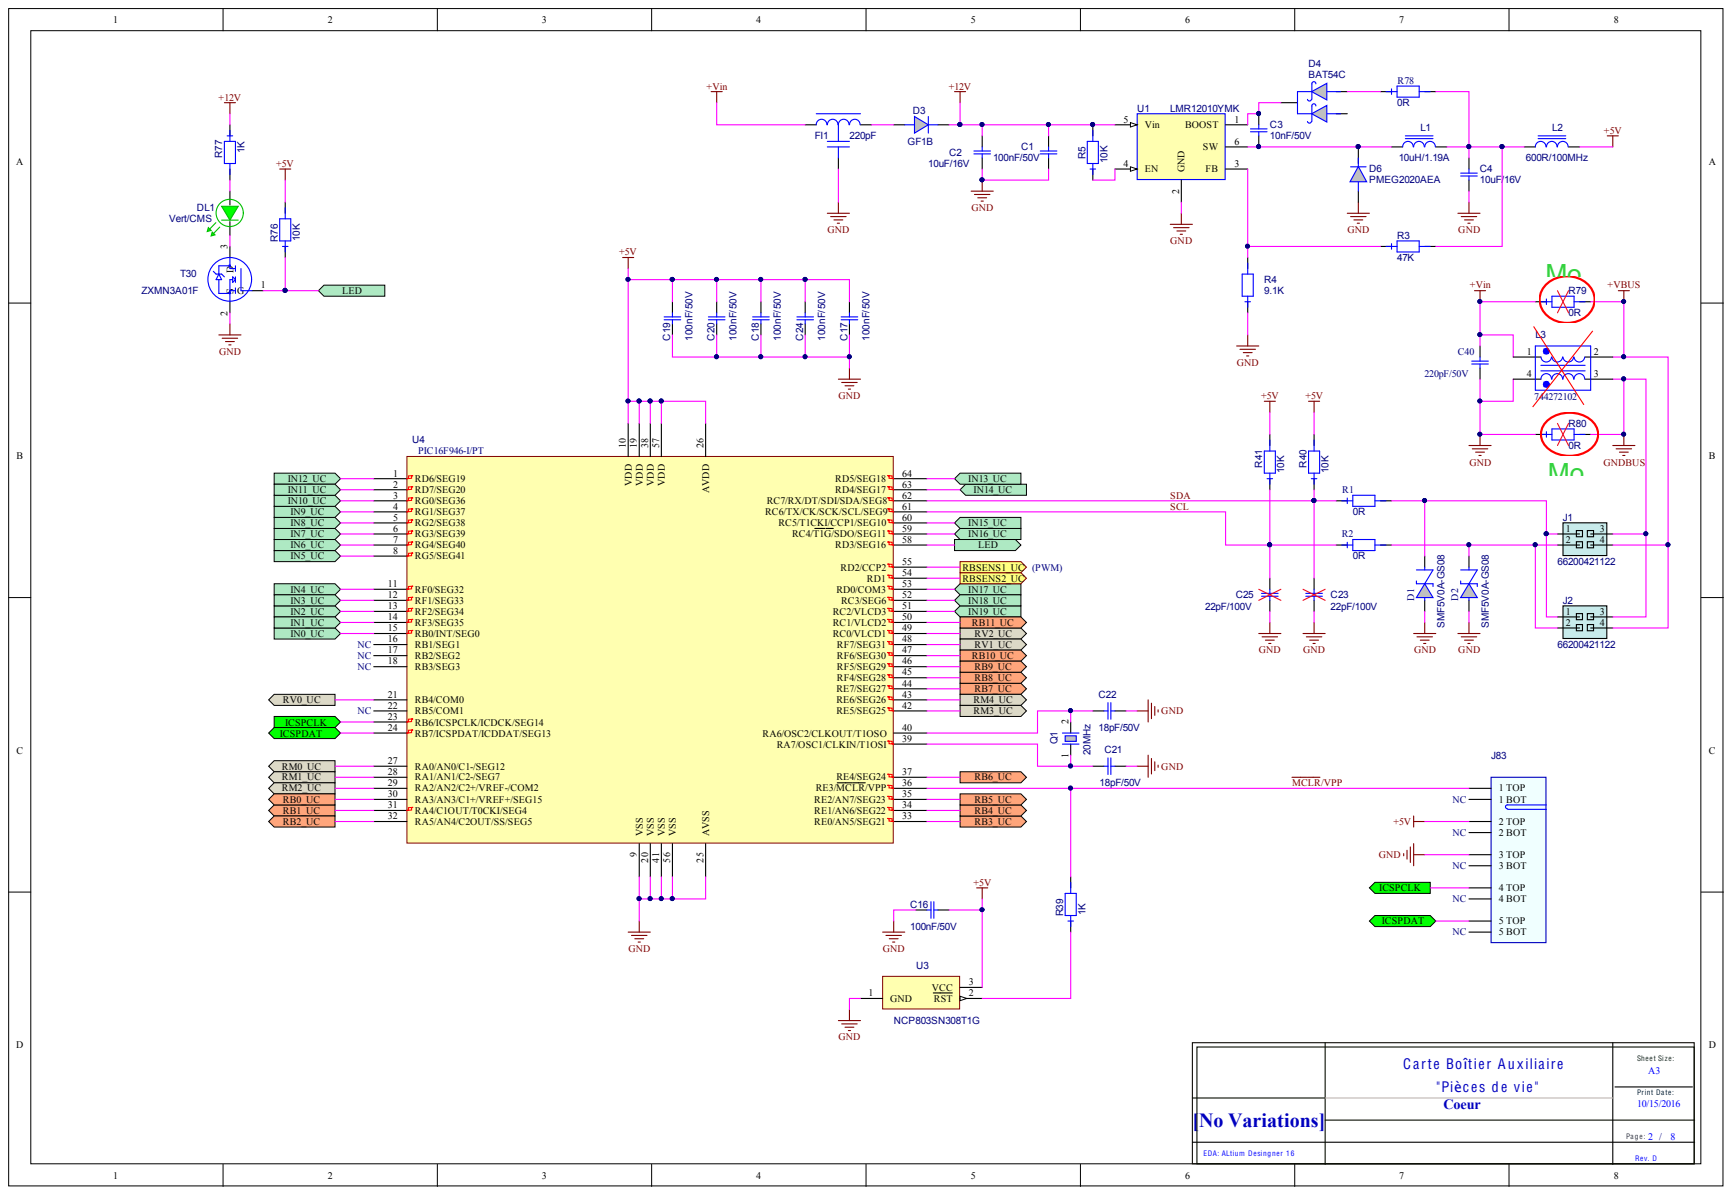
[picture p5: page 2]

L3 | 2

SCL | | 0R R2

[No Variations] | Coeur

EDA: ALtium Desing ner 1 6

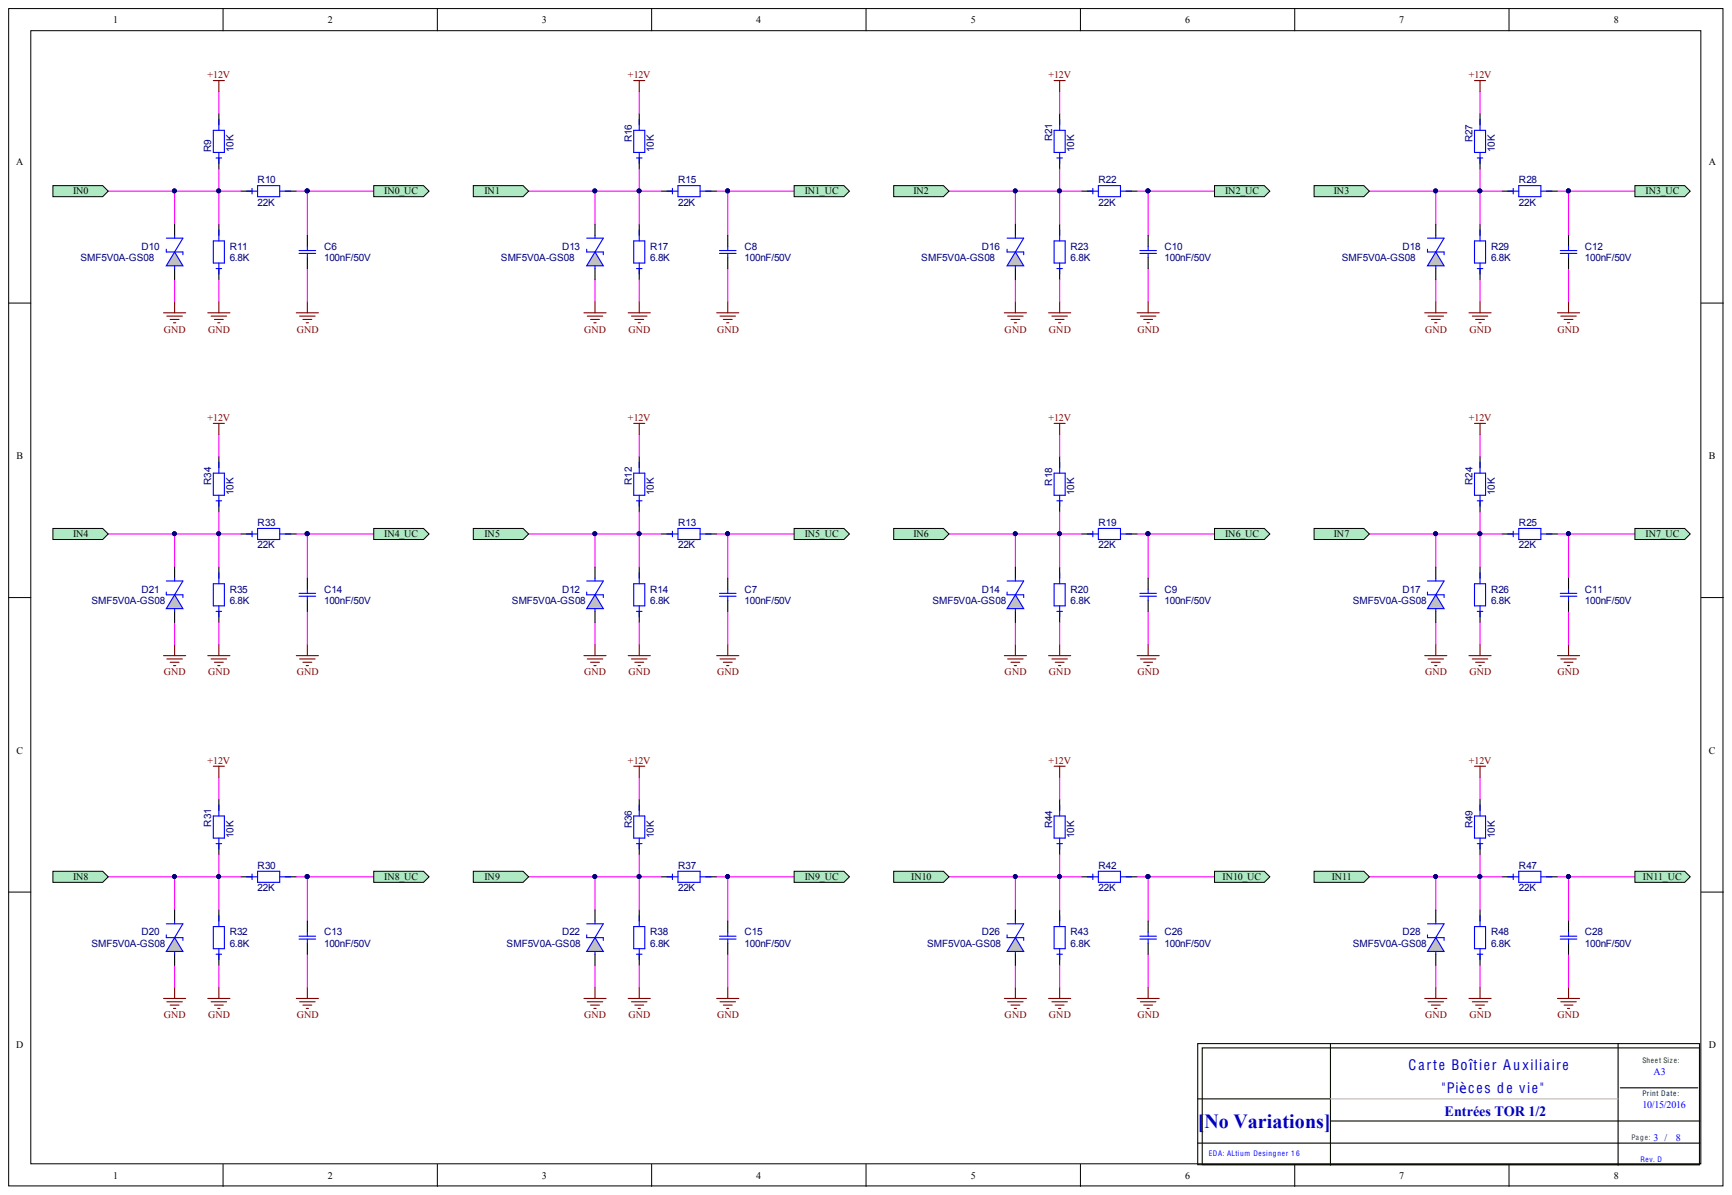
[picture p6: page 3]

[No Variations] | Entrées TOR 1/2

EDA: ALtium Desing ner 1 6

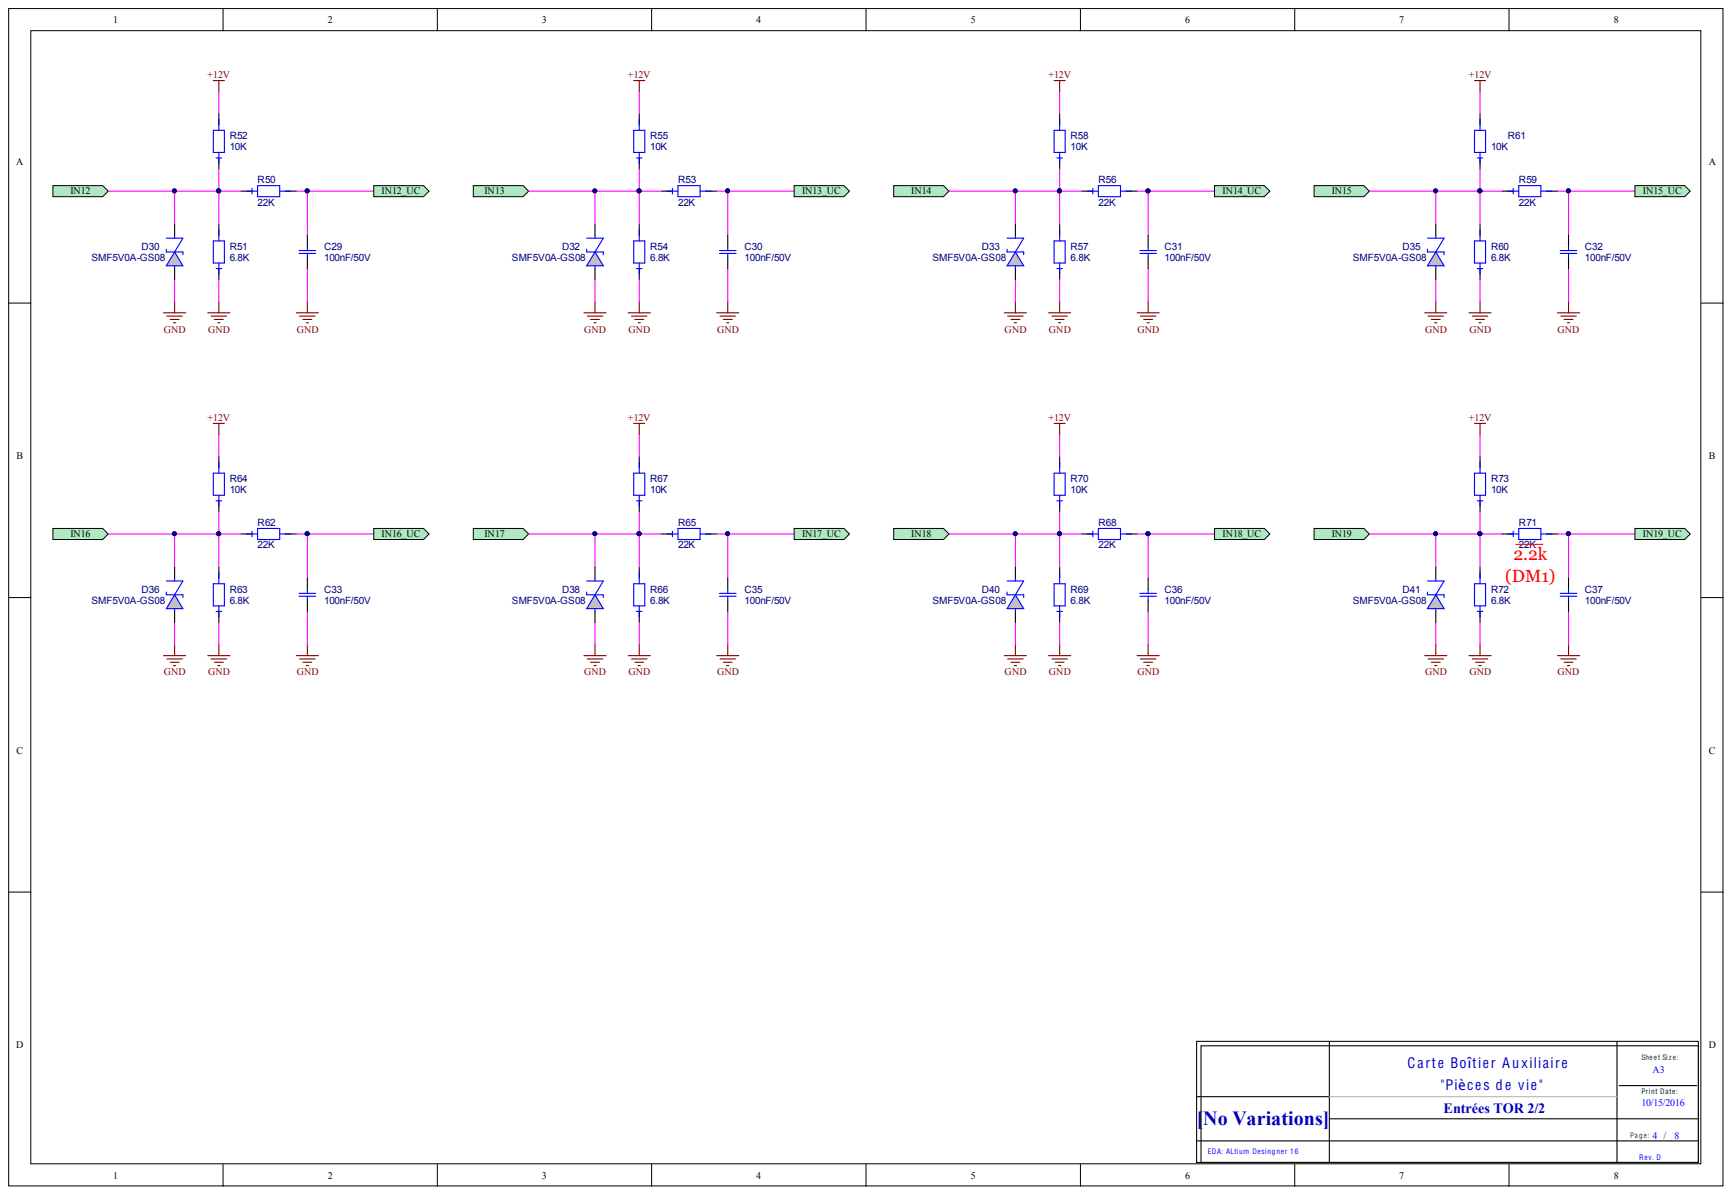
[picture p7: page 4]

EDA: ALtium Desing ner 1 6

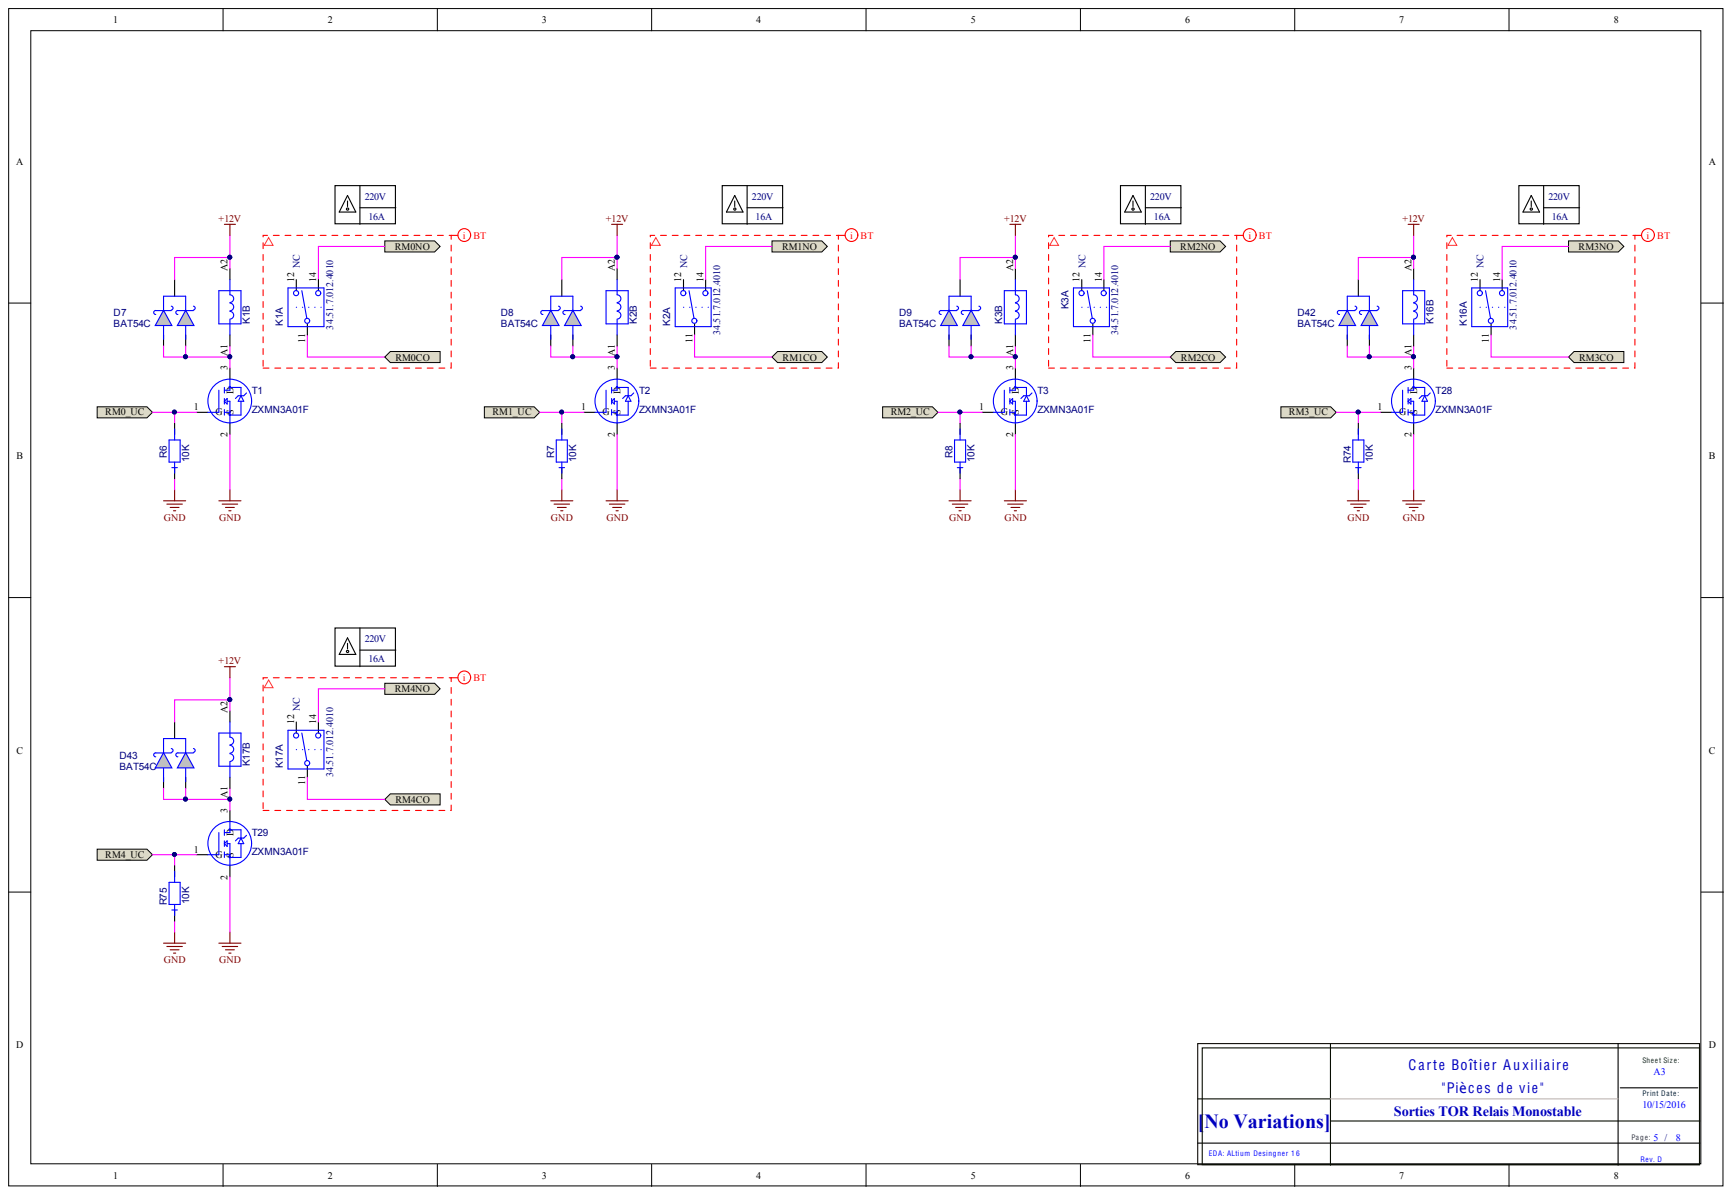
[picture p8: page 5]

[No Variations] | Sorties TOR Relais Monostable

EDA: ALtium Desing ner 1 6

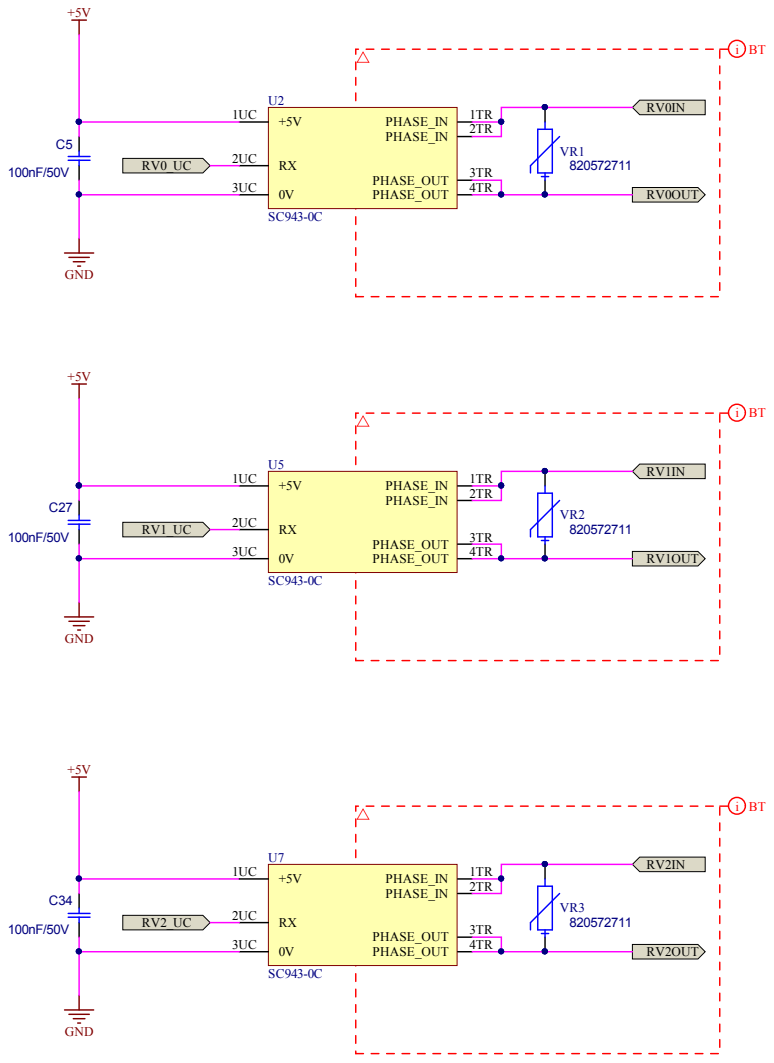
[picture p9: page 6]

+5V 1UC | PHASE_IN
RX 2UC | 2TR

EDA: ALtium Desing ner 1 6

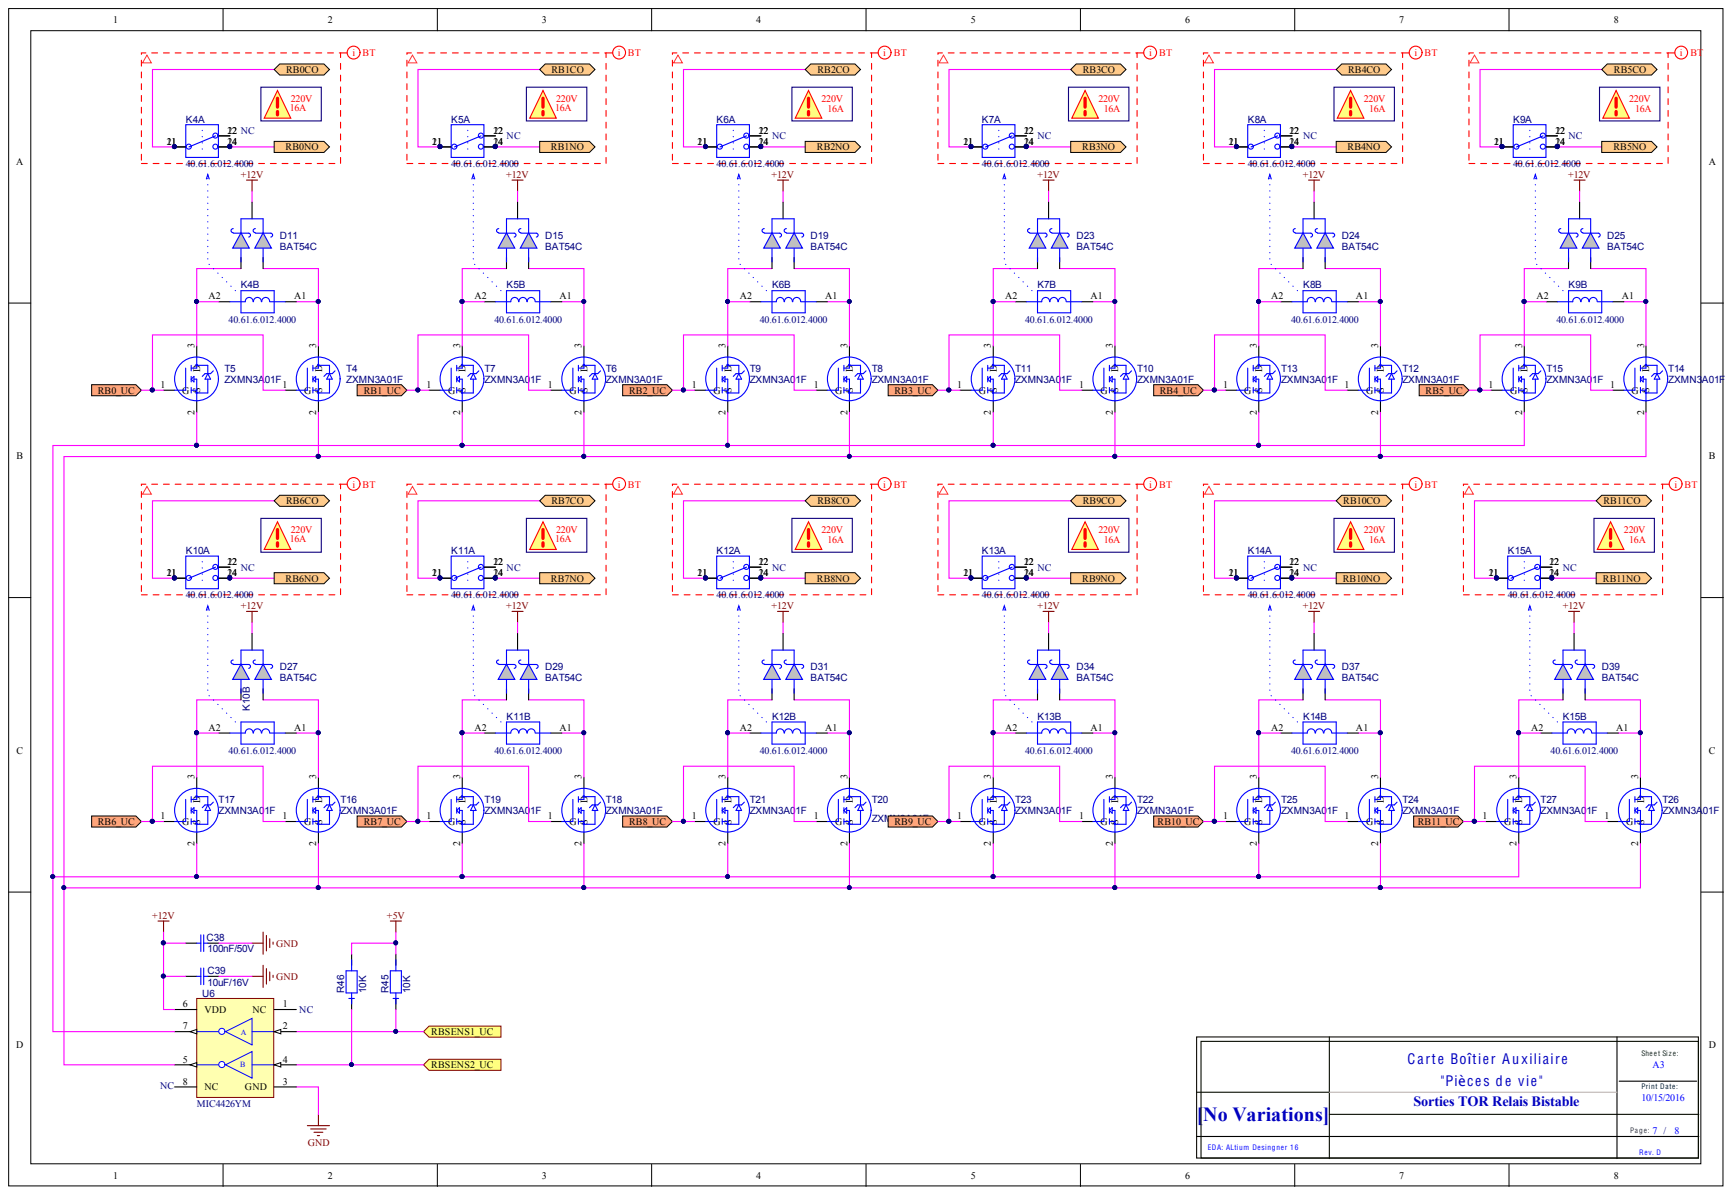
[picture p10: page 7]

[No Variations] | Sorties TOR Relais Bistable

EDA: ALtium Desing ner 1 6 | | Rev. D

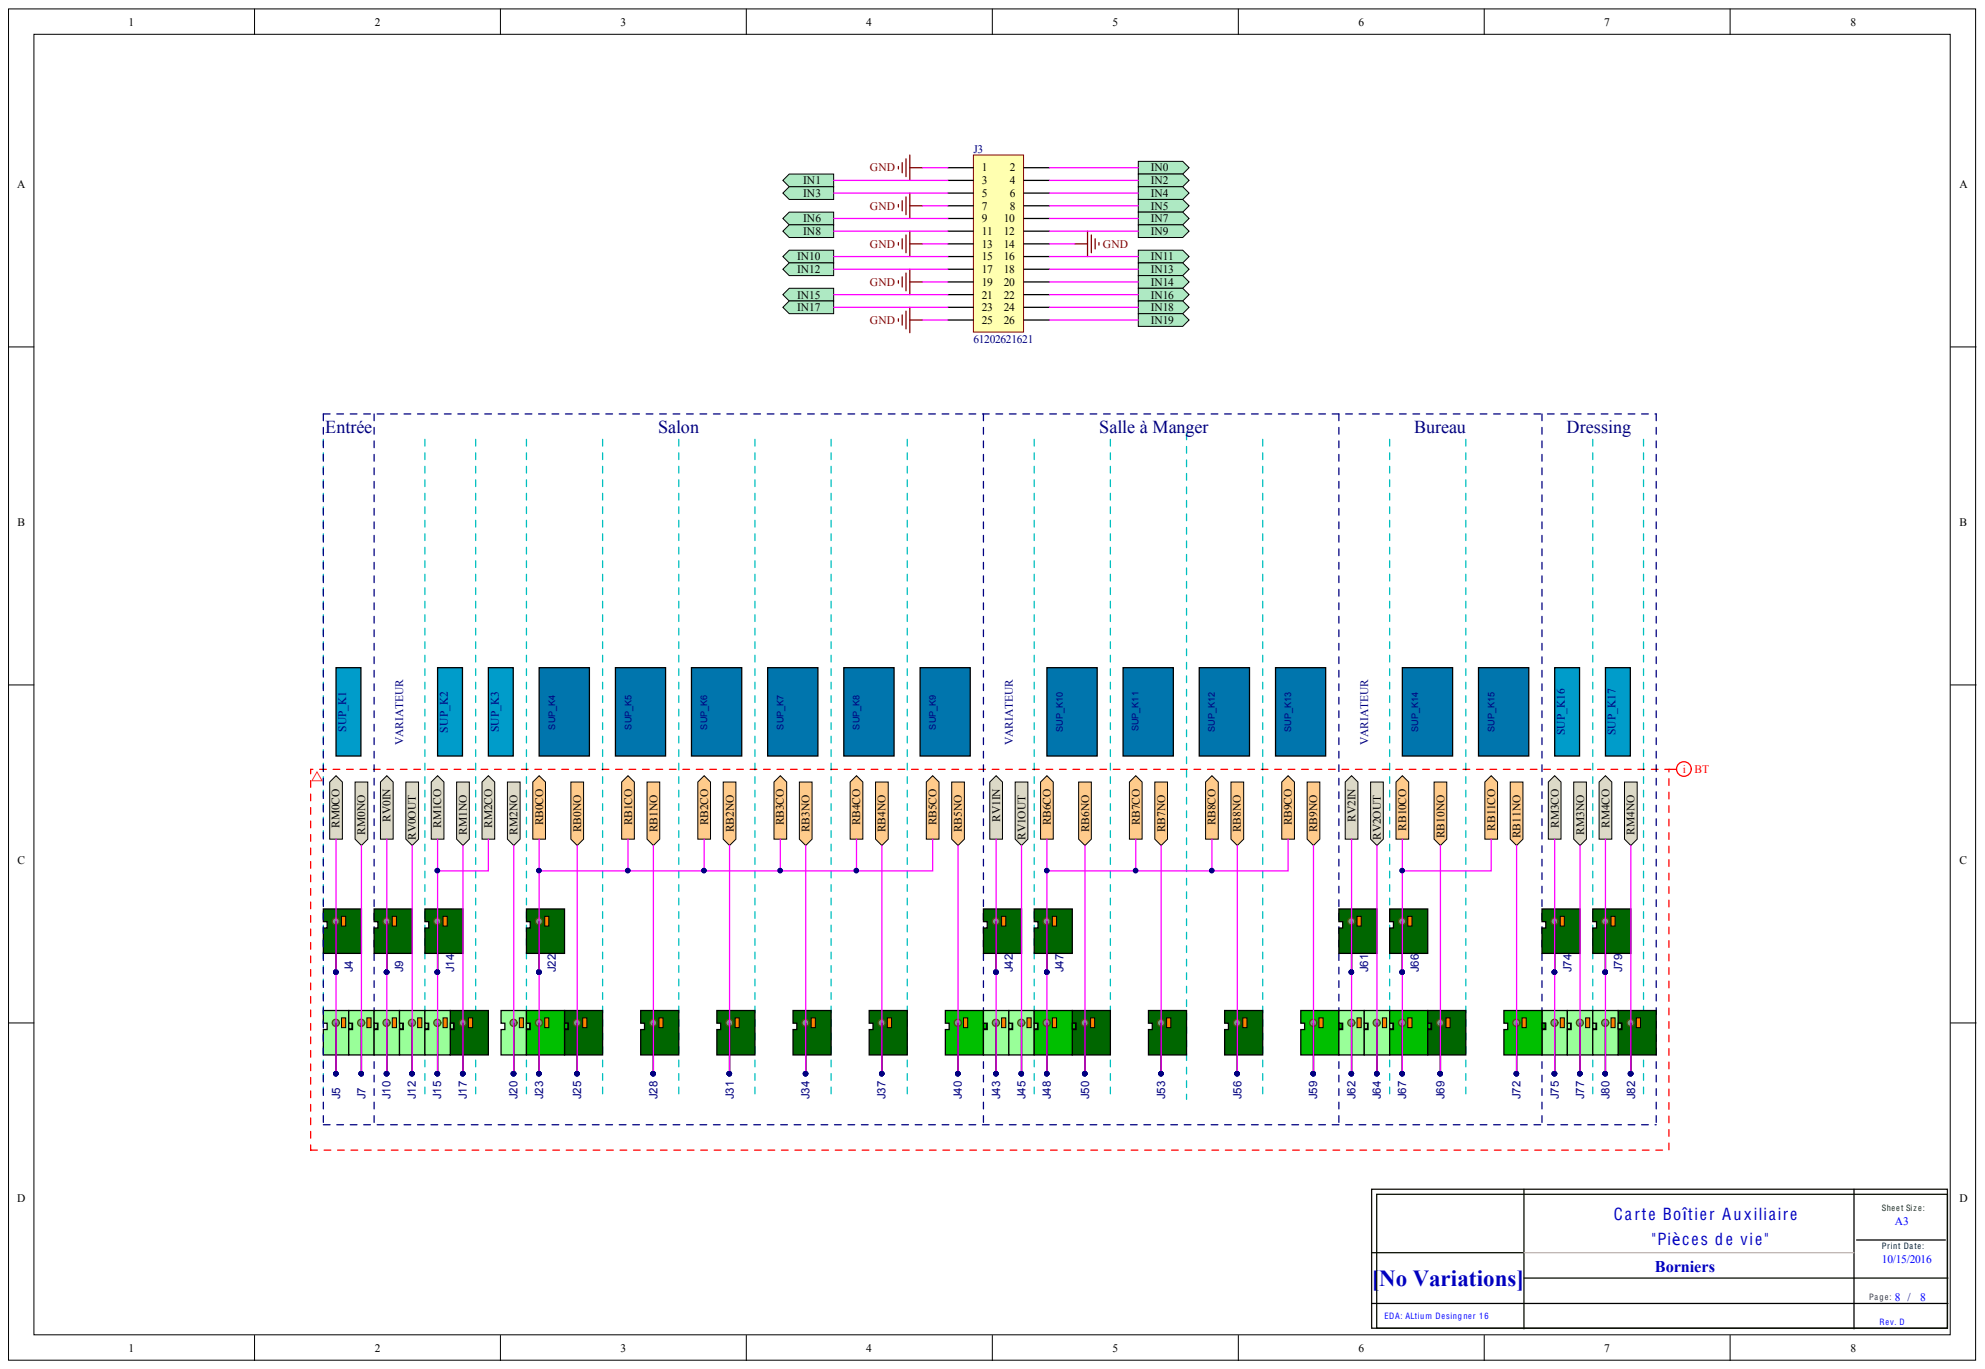
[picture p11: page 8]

[No Variations] | Borniers

EDA: ALtium Desing ner 1 6 | | Rev. D

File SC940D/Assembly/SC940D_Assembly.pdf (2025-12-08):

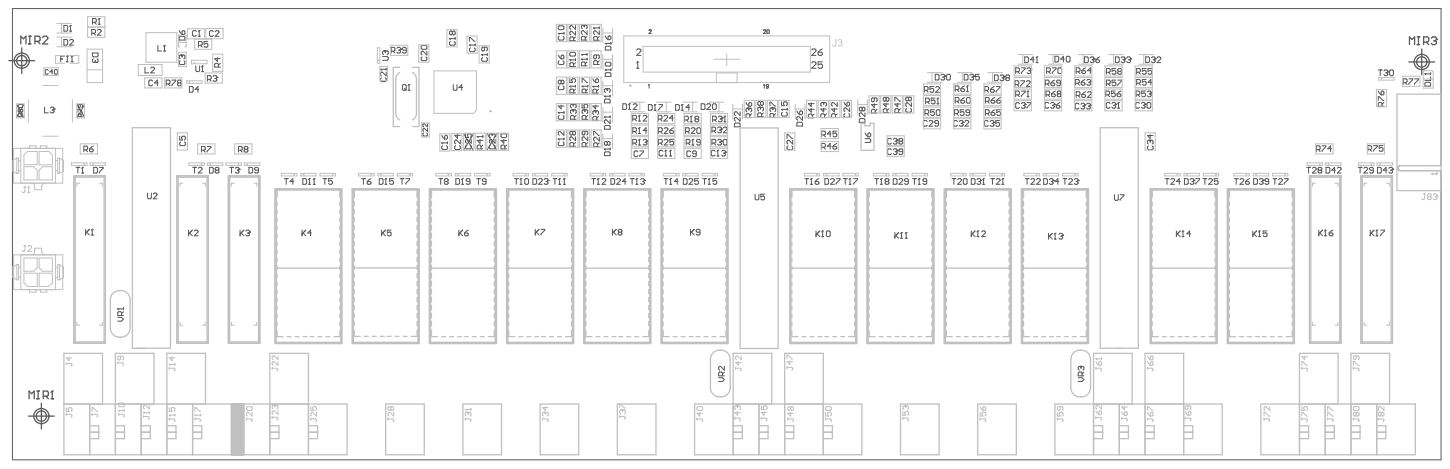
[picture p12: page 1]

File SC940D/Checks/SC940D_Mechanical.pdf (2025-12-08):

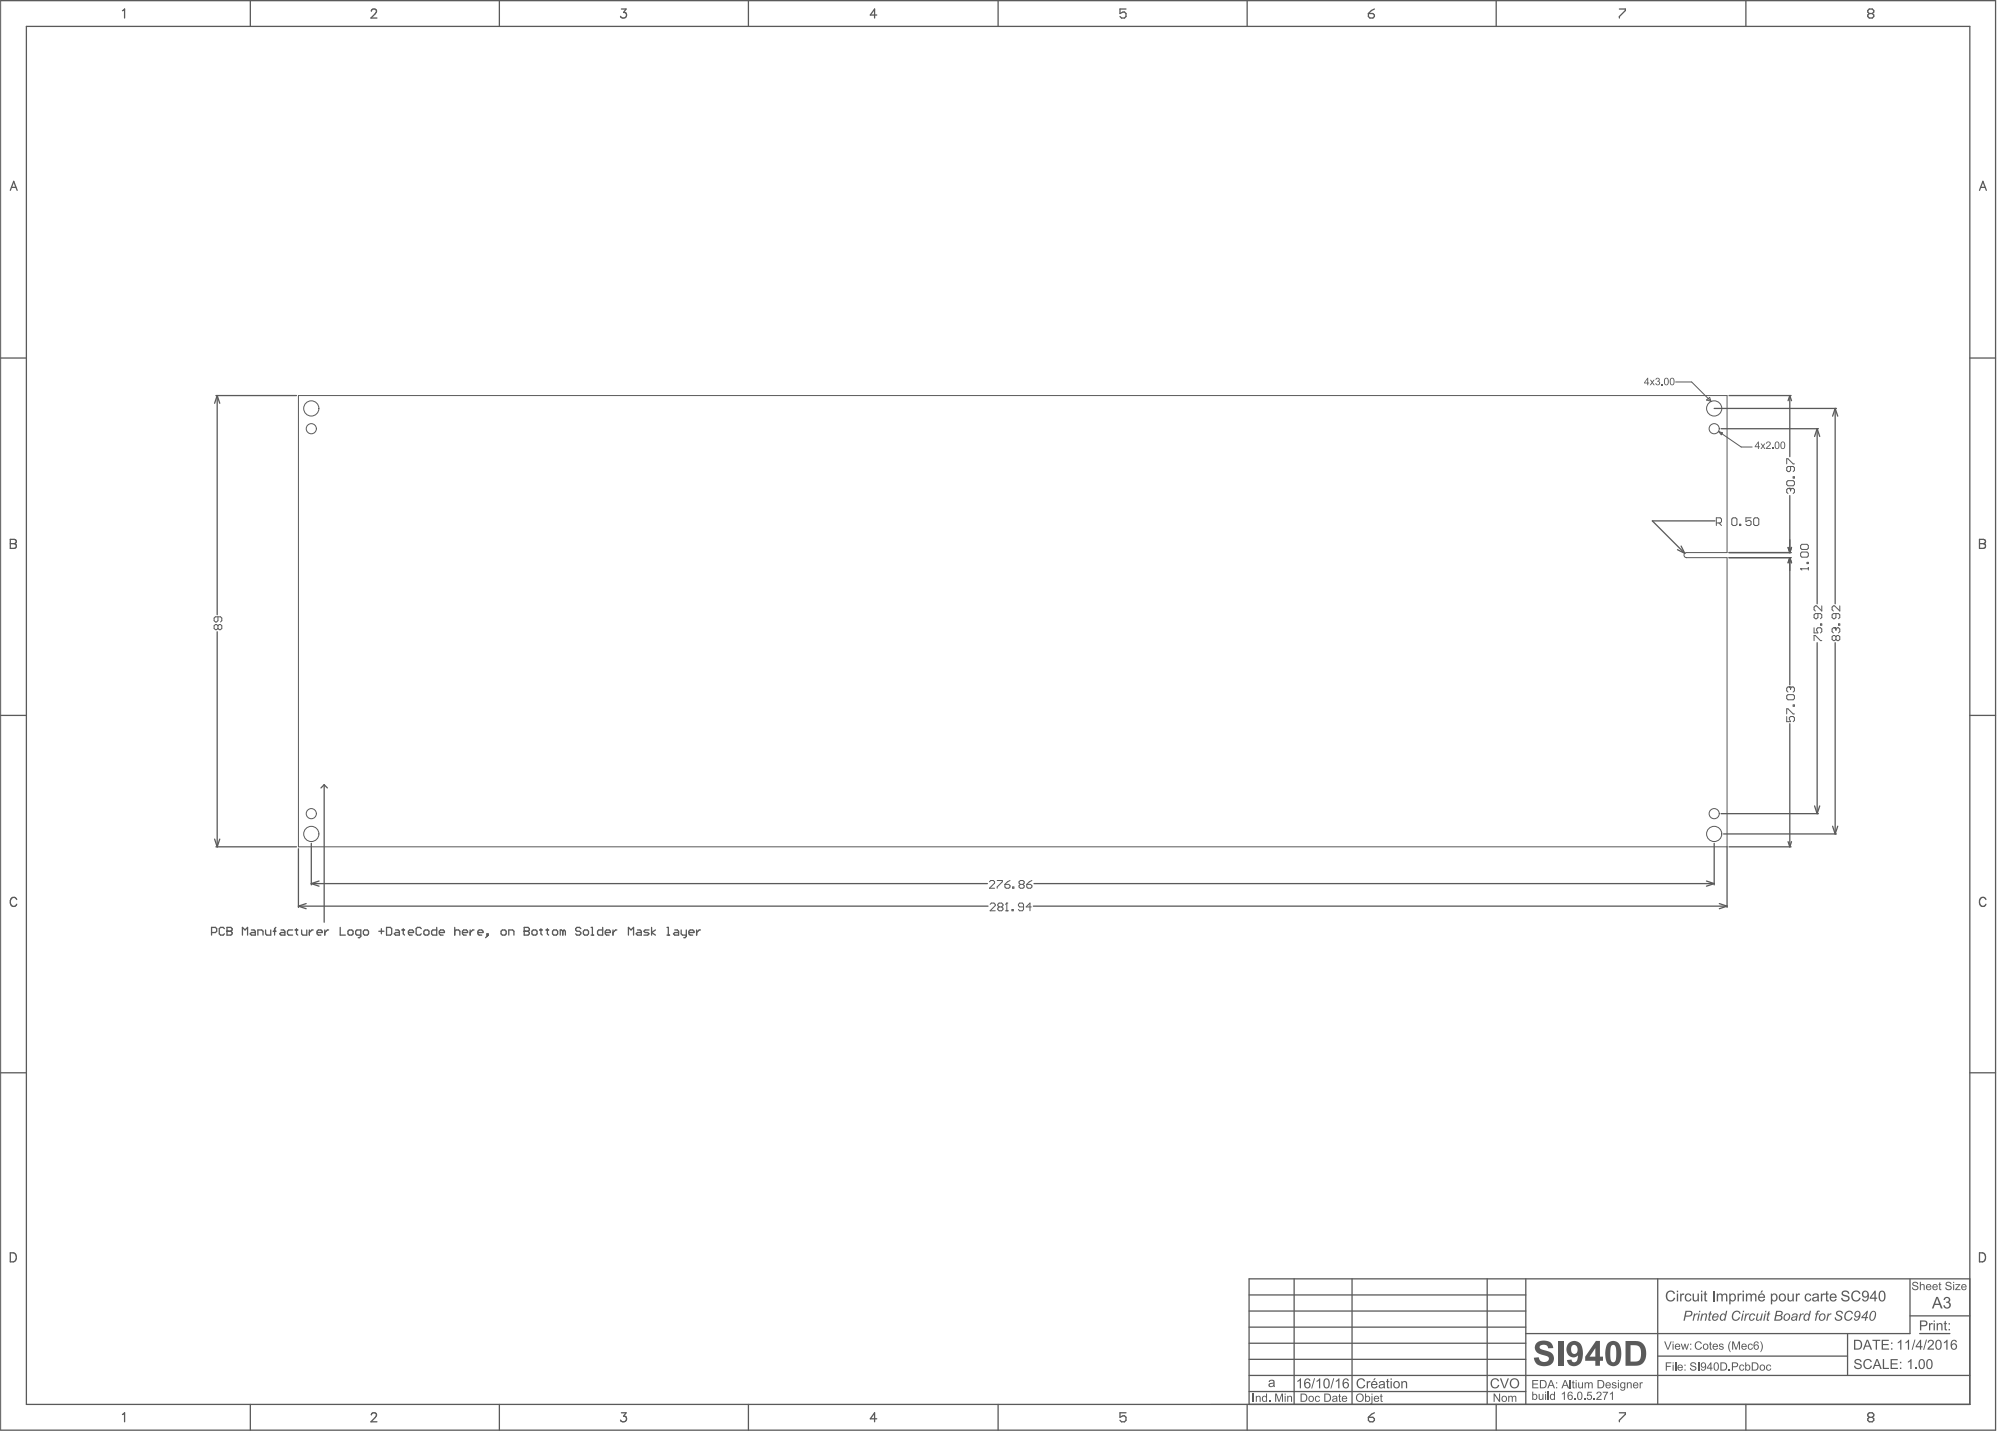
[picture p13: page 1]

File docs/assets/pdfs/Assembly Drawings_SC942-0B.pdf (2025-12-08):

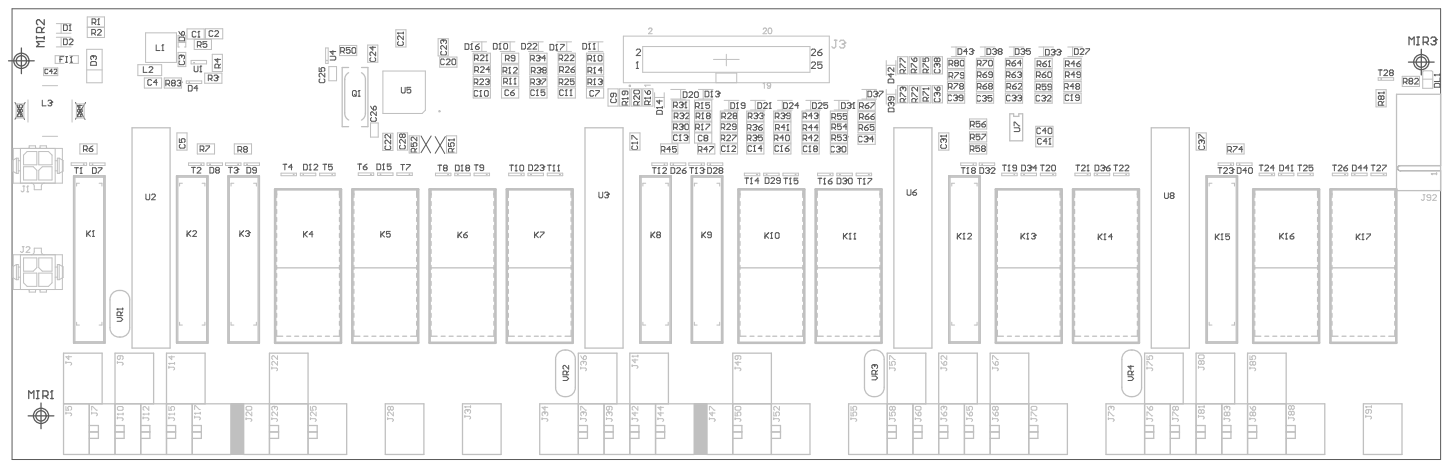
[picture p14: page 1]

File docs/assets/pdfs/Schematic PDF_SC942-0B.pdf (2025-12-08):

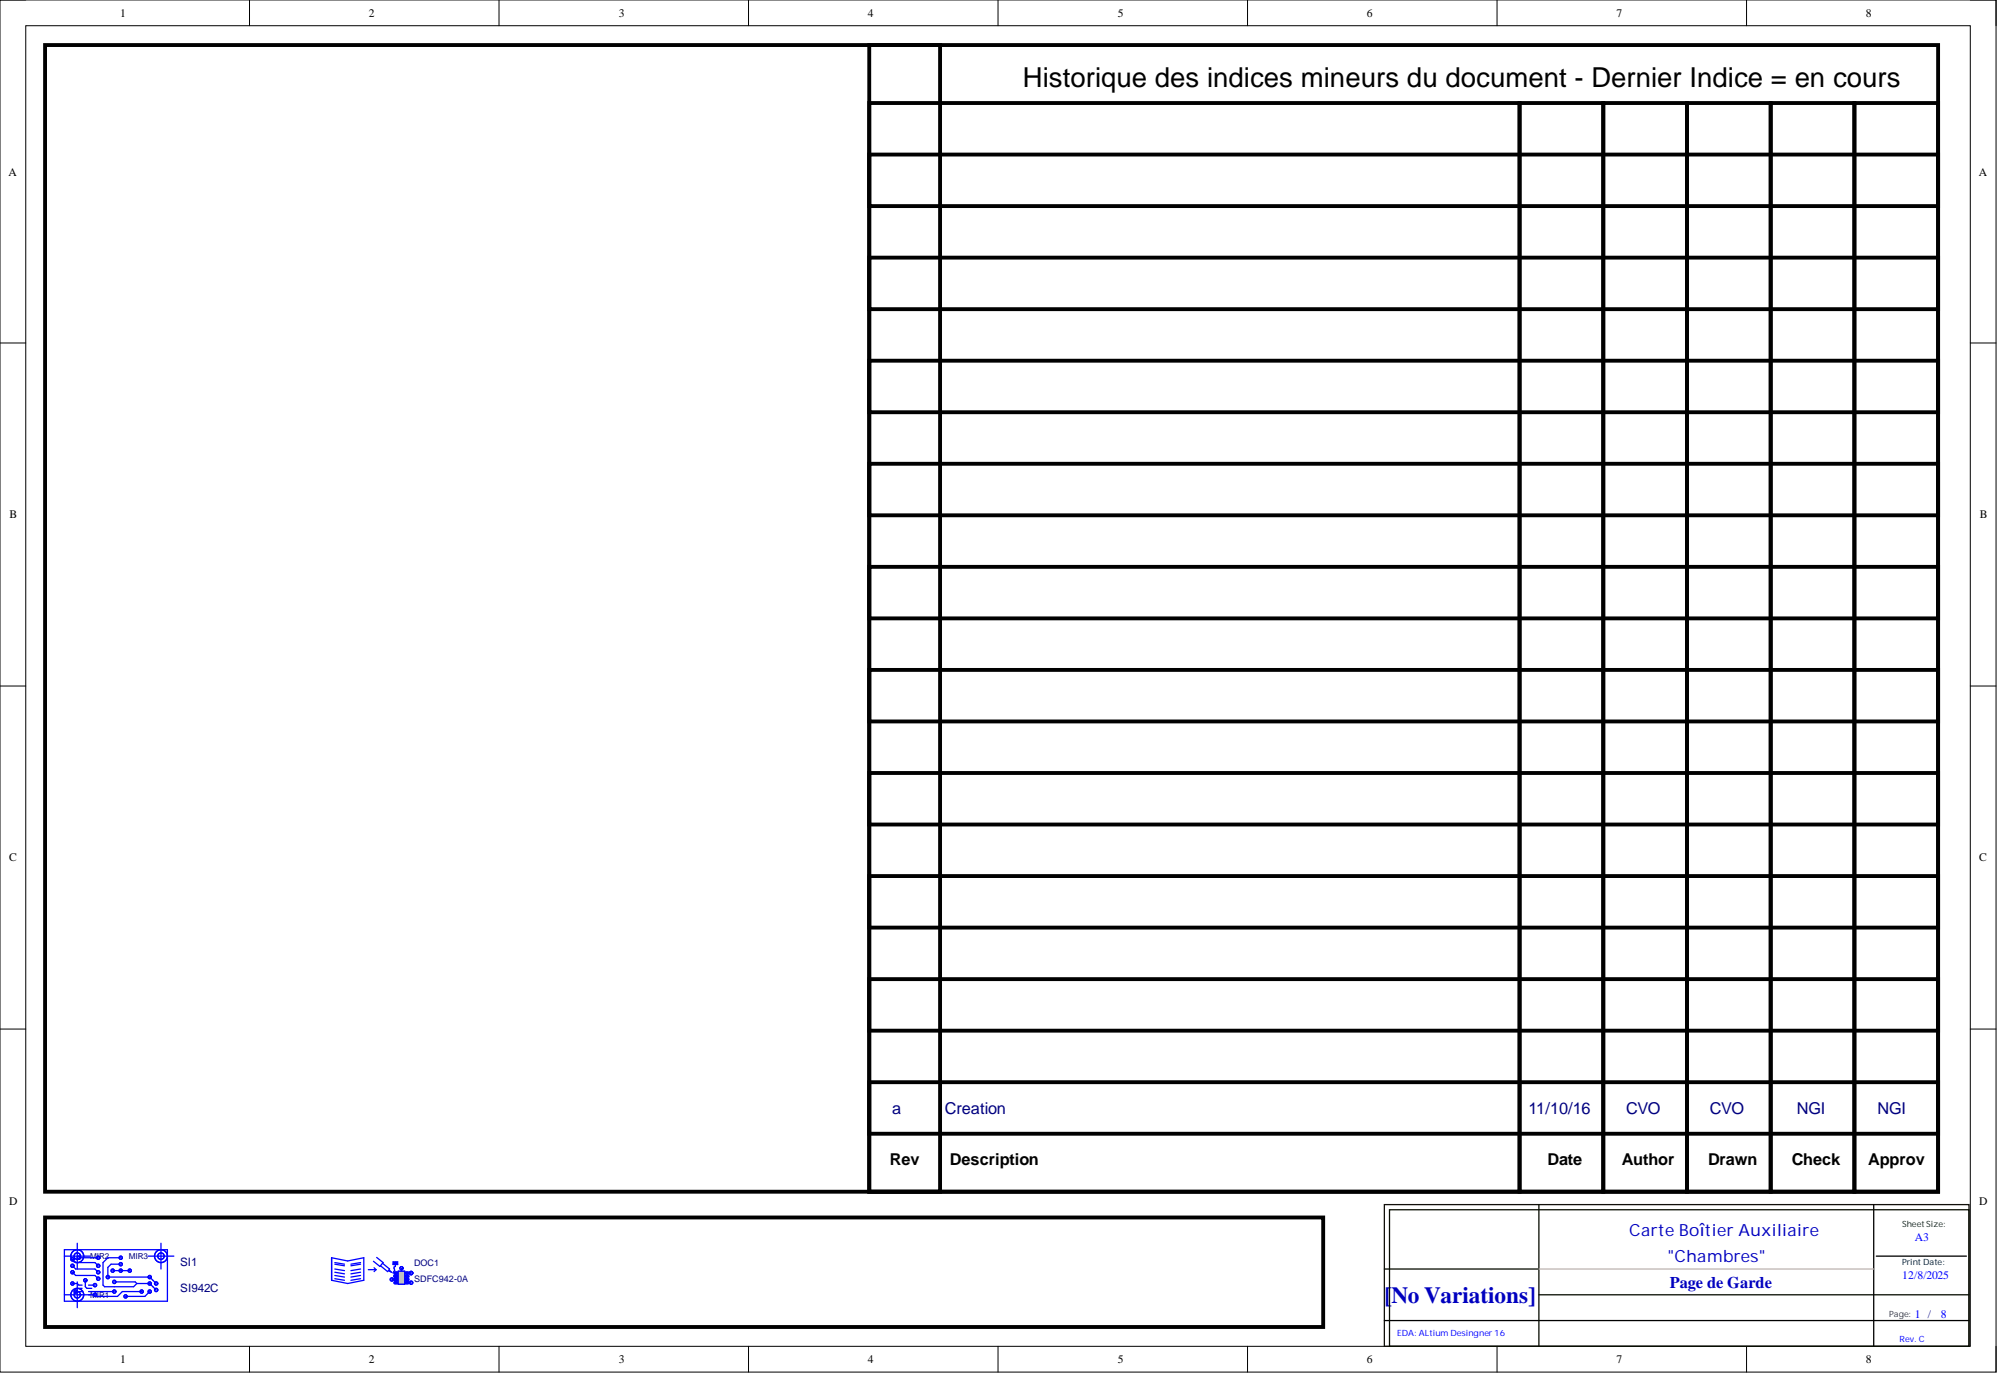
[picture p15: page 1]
t Date:; bres" CODOC1

Historique des indices mineurs du document - Dernier Indice = en cours

a | Creat i o n | 11/10/ 1 6 | C V O | C V O | N G I | N G I

Rev | Descripti o n | Dat e | Autho r | Draw n | Check | Approv

[No Variations] | Page de Garde

Pag e : /

EDA: AL t i u m Des i n g ner | | Rev . C


SCL

Coeur

Pag e : /

EDA: AL t i u m Des i n g ner | | Rev . C


Page:

EDA: ALtium Desingner 16 | | Rev. C



Sorties TOR Relais Monostable



"Chambres"
Sorties TOR Relais Bistable





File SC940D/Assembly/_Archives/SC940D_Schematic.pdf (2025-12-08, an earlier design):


a | Cr e atio n | 1 1/1 0/1 6 | CV O | CV O | NGI | NGI

Re v | De s cription | Da t e | Author | Drawn | Che c k | Approv

C a r t e B o î tie r Auxiliair e " P i è c es d e vie " | S h e e t Size : A 3

[No Variations] | P a ge de Garde

E D A : A L tium D esin g n e r 1 6 | | R e v . D


L3 | 2

SCL | | 0R R2

[No Variations] | Coeur

Page: 2 / 8

EDA: ALtium Desingner 16 | | Rev. D


[No Variations] | Entrées TOR 1/2

Page: 3 / 8

EDA: ALtium Desingner 16


EDA: ALtium Desingner 16

Page: 4 / 8


[No Variations] | Sorties TOR Relais Monostable

Page: 5 / 8

EDA: ALtium Desingner 16


+5V 1UC | PHASE_IN
RX 2UC | 2TR

EDA: ALtium Desingner 16

Page: 6 / 8


[No Variations] | Sorties TOR Relais Bistable

Page: 7 / 8

EDA: ALtium Desingner 16 | | Rev. D


[No Variations] | Borniers

Page: 8 / 8

EDA: ALtium Desingner 16 | | Rev. D

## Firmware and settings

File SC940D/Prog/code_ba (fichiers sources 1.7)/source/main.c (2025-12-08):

#include <htc.h>
#include "traitement.h"
#include "hard.h"
#include "constantes.h"
#include "struct.h"
#include "global.h"
#include "gestionentrees.h"
#include "gestionsorties.h"
#include "variateur.h"

extern  void SSP_Handler(void);
extern void vd_I2C_Setup(void);
extern void vd_Traitement_I2C(void);

__CONFIG(HS & WDTDIS); // CONFIG MICRO : HORLOGE HS / PAS DE WDG (AU DEMARRAGE)

// ----------------------- VERSION ----------------------

#define VERSION_EEPROM  1       // mémorisée en eeprom après 1ière écriture
                                // utilisée pour réinitialiser l'eeprom en cas d'évolution du mapping
                                // à incrémenter à chaque fois que le mapping eeprom change


// IR 13/03/13 : reprise mapping eeprom / ajout temps d'extinction et temps d'action
// mapping eeprom : tous boitiers 
// 0x000D   version mapping eeprom : pour gestion compatibilité eeprom
// 0x000E   test eeprom : 0x55 si initialisée au moins une fois
// 0x000F   test eeprom : 0xAA si initialisée au moins une fois
// 0x0010   sorties lampes / relais monostables (LSB)
// 0x0011   sorties lampes / relais monostables (MSB)
// 0x0012   variateur 1 : allumage en cours
// 0x0013   variateur 1 : allumage sauvegardé
// 0x0014   variateur 1 : configuration des variateurs
// 0x0015   variateur 2 : allumage en cours
// 0x0016   variateur 2 : allumage sauvegardé
// 0x0017   variateur 2 : configuration des variateurs
// 0x0018 - 0x0029  variateurs 3 à 8
// 0x002A   volet 1 : temps d'action
// 0x002B   volet 2 : temps d'action   
// 0x002C - 0x0031 : volets 3 à 8
// 0x0032   lampe 1 : temps d'extinction
// 0x0033   lampe 2 : temps d'extinction
// 0x0034 - 0x0042 : lampes 3 à 15
// 0x0042   compteur d'écriture en eeprom (etats)


//-------------------------------------- eeprom

// vérification version d'eeprom
void vd_Verif_Version (void)
{
    unsigned char   l_uc_Data;
    unsigned int    address = 0x000D;

    l_uc_Data = eeprom_read(address++);
    if (l_uc_Data != VERSION_EEPROM)
    {
        // efface les octets de test pour forcer l'initialisation de l'eeprom
        eeprom_write(address++, 0);
        eeprom_write(address, 0);
    }
}

// lecture données sauvegardées en eeprom
void vd_Lit_Config (void)
{
	unsigned char l_uc_Compteur;
//	unsigned char l_uc_Masque;
//	unsigned char data;
	unsigned int address = 0x000E;
        unsigned short  l_us_Test = 0;

 	l_us_Test = eeprom_read(address++);
	l_us_Test |= (eeprom_read(address++) << 8);
        if (l_us_Test == 0xAA55)
        {
            // eeprom déja programmée : lecture des données sauvegardées

            // lampes / relais simples

            us_SortiesRelais = eeprom_read(address++);
            us_SortiesRelais |= (eeprom_read(address++) << 8);

            // variateur

            // pour chaque variateur : allumage en cours, allumage sauvegardé et configuration
            for(l_uc_Compteur=0;l_uc_Compteur<uc_VARIATEUR_NB;l_uc_Compteur++)
            {
                st_Variateurs[l_uc_Compteur].c_Eclairage = eeprom_read(address++);
                st_Variateurs[l_uc_Compteur].c_EclairageOld = eeprom_read(address++);
                st_EntreesVariateur[l_uc_Compteur].ub3_EntreeMode = eeprom_read(address++) & 0x07;
             }

            // pour chaque volet : temps d'action
            address = 0x002A;
            for (l_uc_Compteur = 0; l_uc_Compteur < VOLET_NB; l_uc_Compteur++)
            {
                uc_TempsCdeVolet[l_uc_Compteur] = eeprom_read(address++);
            }

            // pour chaque lampe : temps d'extinction
            address = 0x0032;
            for (l_uc_Compteur = 0; l_uc_Compteur < RM_NB; l_uc_Compteur++)
            {
                uc_TempsCdeLampe[l_uc_Compteur] = eeprom_read(address++);
            }

            // compteur de surveillance écrit en dernier
            address = 0x0042;
            uc_compteur_lecture_eeprom = eeprom_read(address);

        }
        else
        {
            // eeprom mauvaise : écriture par défaut

            // lampes / relais simples

            eeprom_write(address++, 0);
            eeprom_write(address++, 0);
            us_SortiesRelais = 0;

            // variateur

            // pour chaque variateur : allumage en cours, allumage sauvegardé, configuration
            for(l_uc_Compteur=0;l_uc_Compteur<uc_VARIATEUR_NB;l_uc_Compteur++)
            {
                eeprom_write(address++, 0);
                eeprom_write(address++, 0);
                st_Variateurs[l_uc_Compteur].c_Eclairage = 0;
                st_Variateurs[l_uc_Compteur].c_EclairageOld = 0;
                eeprom_write(address++, uc_MODE_VARIATEUR);  // par défaut : mode variateur
                st_EntreesVariateur[l_uc_Compteur].ub3_EntreeMode = uc_MODE_VARIATEUR;
            }

            // pour chaque volet : temps d'action
            address = 0x002A;
            for (l_uc_Compteur = 0; l_uc_Compteur < VOLET_NB; l_uc_Compteur++)
            {
#ifdef TYPE_PIECES_D_EAU
                if(l_uc_Compteur == 3)
                {
                        // Par défaut pour store -> durée différente !
                        uc_TempsCdeVolet[l_uc_Compteur] = uc_TEMPS_CDE_STORE_DEFAUT;
                }
                else
#endif
                {
                        uc_TempsCdeVolet[l_uc_Compteur] = uc_TEMPS_CDE_VOLET_DEFAUT;
                }
                eeprom_write(address++, uc_TempsCdeVolet[l_uc_Compteur]);
            }

            // pour chaque lampe : temps d'extinction
            address = 0x0032;
            for (l_uc_Compteur = 0; l_uc_Compteur < RM_NB; l_uc_Compteur++)
            {
                eeprom_write(address++, 0);     // par défaut : pas d'extinction
                uc_TempsCdeLampe[l_uc_Compteur] = 0;
            }

            // compteur de surveillance écrit en dernier
            address = 0x0042;
            uc_compteur_lecture_eeprom = 0;
            eeprom_write(address++, uc_compteur_lecture_eeprom);

            address = 0x000D;
            eeprom_write(address++, VERSION_EEPROM);     //version
            eeprom_write(address++, 0x55);     //octet de test
            eeprom_write(address++, 0xAA);     //octet de test
        }

}

// sauvegarde des données en eeprom
// sauvegarde de l'état des lampes
// les données de configuration sont stockées lorsqu'elles sont reçues
void vd_Sauve_Etat (void)
{
	unsigned char l_uc_Compteur;
	unsigned char data;
	unsigned int address = 0x0010;

	// lampes / relais simples

	data = us_SortiesRelais & 0x00FF;
	eeprom_write(address++, data);
	data = us_SortiesRelais >> 8;
	eeprom_write(address++, data);

	// volets
	// pas de mémorisations de l'état des relais : seront mis à l'arrêt au redémarrage

	// variateurs

	// pour chaque variateur : allumage en cours et allumage sauvegardé
	for(l_uc_Compteur=0;l_uc_Compteur<uc_VARIATEUR_NB;l_uc_Compteur++)
	{
            eeprom_write(address++, st_Variateurs[l_uc_Compteur].c_Eclairage);
            eeprom_write(address++, st_Variateurs[l_uc_Compteur].c_EclairageOld);
            address++;
        }

	// compteur de surveillance écrit en dernier
        address = 0x0042;
	uc_compteur_ecriture_eeprom = eeprom_read(address)+1;
	if (uc_compteur_ecriture_eeprom >= 255)
		uc_compteur_ecriture_eeprom = 1;
	eeprom_write(address, uc_compteur_ecriture_eeprom);

}

//-------------------------------------- interruption

// Exécuté en cas d'IT (timer, I2C)
void interrupt IT(void)
{
    static unsigned char s_uc_TempoStart = 0;

// xxx essai par vrai PWM xxx 	
// bascule sur IT timer 0 : timer 2 réservé au PWM
// !!! timer 0 lié à la gestion du watch dog => passé sur timer 1
//	if((PIR1 & 0x02) != 0)
	if (T0IF==1 && T0IE==1)
// xxx fin essai par vrai PWM xxx 	
	{
		// IT Timer
		// traitement ecrit directement ici à cause de la faible profondeur de la pile
		// Cadencement traitement cycle / acquisition des entrées
		// Commande en "PWM" des relais bistable
		// Commande en "liaison série" des variateurs

		uc_FlagITTimer = 1;
		
		uc_CompteurAcq++;		// acquisition des entrées déplacée dans la tache de fond, pour que le traitement de l'IT soit court
		//uc_CompteurVar++;
	
		// commande des variateurs
                if(s_uc_TempoStart < 50)    // Tempo au start environ 20 ms : laisser le temps a la ligne de comm de stabiliser avant d'envoyer la commande
                {
                    s_uc_TempoStart++;
                }
                else
                {
                    vd_PilotageVariateurs();
                }
	
		// fin traitement IT Timer

		TMR0-=uc_TIMER_416_US;	 //[PDP_2012-10-22]_Erreur Init fixed					// timer initialisé
		T0IF=0;
	}

	/* xxx gestion chute de tension : ne marche pas sur ce hard
	// IT chute de tension 
	if((LVDIF != 0) && (LVDIE !=0))
	{
		// IT chute de tension 
		if (ub1_Tension_OK !=0)
		{	// surveillance chute de tension active
			if (ub1_Tension_Chute ==0)
			{
				vd_Sauve_Config ();
				ub1_Tension_Chute = 1;
				ub1_Tension_ChuteIT = 1;
			}
		}
		// fin traitement IT chute de tension 
		LVDIF =0;
	}
	xxx */

    // I2C
    if(SSPIF)
    {
        SSPIF = 0; // Clear the interrupt flag.

        if (SSPIE == 1)
        {
            // IT autorisée
            SSP_Handler(); // Do I2C communication
        }
    }

}

//-------------------------------------- principal

void main(void)
{
	vd_InitVariables();	// !!! A FAIRE AVANT TOUTE AUTRE FONCTION
	vd_InitMicro();
        vd_I2C_Setup();
	vd_ConfigBornier();	// lit le type de bornier pour initialiser les valeurs max
        vd_Verif_Version();     // vérification version
	vd_Lit_Config ();	// lecture des paramètres sauvegardés en eeprom
	vd_InitVariables2();	// IR 14/03/2013 init scindée pour prise en compte des valeurs lues en eeprom

        GIE = 1;
        PEIE = 1;

	// attend 1 nouveau cycle pour autoriser la sortie PWM (init du PWM)
	while(TMR2IF == 1)
	{
		PWM_INIT_OUT		// bascule en sortie à la fin du 1er cycle
		TMR2IF = 0;
	}

	while(1)
	{

		vd_ConfigBornier();		// confirme le type de bornier


                /* xxx traitement chute de tension : ne fonctionne pas sur ce hard
                // chute de tension
                if (IRVST !=0)
                {	// Indicates that the PLVD is stable and PLVD interrupt is reliable
                        if (ub1_Tension_OK == 0)
                        {	// indique "tension stable vue à la mise sous tension" => la surveillance peut commencer
                                ub1_Tension_OK = 1;
                                LVDIF =0;
                        }
                        if (LVDIE == 0)
                        {	// autorise l'interruption sur chute de tension, dès que la tension est stable à la mise sous tension
                                LVDIE = 1;	// Enables Low Voltage Detect Interrupt
                        }
                }
                if (ub1_Tension_OK !=0)
                {	// surveillance chute de tension active
                        if (LVDIF !=0)
                        {	// chute de tension détectée
                                if (ub1_Tension_Chute ==0)
                                {
                                        // xxw vd_Sauve_Config ();
                                        // xxx ub1_Tension_Chute = 1;
                                        ;	// traitement se passe en IT
                                }
                                LVDIF =0;
                        }
                }
                // xxx tests
                // if (RF1 == 0)	// entrée 3
                //	LVDIF =1;		// simulation par entrée
                xxx fin traitement chute de tension */

                // eeprom
                // IR 14/03/2013 Sauvegarde déplacée dans le traitement I2C pour prendre en compte le front uniquement
                //if (st_Commandes.ub1.Sauvegarde ==1)
                //{
                //        vd_Sauve_Etat ();
                //        st_Commandes.ub1.Sauvegarde = 0;    // raz commande une fois traitée
                //}


// Cadencement acquisition des entrées : [5ms]
// Traitement entrées DIN (anti rebond, simple appui / double appui / appui long)
// traitement fin de commande des relais bistables
		if(uc_CompteurAcq >= uc_ACQ)
		{
			uc_CompteurAcq -= uc_ACQ;	// prend en compte le retard de traitement
			if (uc_CompteurAcq > 100)
				uc_CompteurAcq = 0;		// pour sécurité et surveillance avec l'émulateur

			uc_CompteurCycle++;
		
			vd_AcquisitionEntrees();
		
			if (uc_CompteurBiStable >0)
			{	// impulsion de commande de relais bi stable en cours
				uc_CompteurBiStable--;
				if (uc_CompteurBiStable ==0)
				{	// impulsions à terminer
					vd_ArretPilotageRelaisBist();
				}
			}

		}

// Cadencement rampes variateurs : [25ms]
//		if(uc_CompteurVar >= uc_VAR)
//		{
//			uc_CompteurVar -= uc_VAR;	// prend en compte le retard de traitement
//			if (uc_CompteurVar > 100)
//				uc_CompteurVar = 0;		// pour sécurité et surveillance avec l'émulateur
//
//			vd_RampeVariateurs();
//
//		}

// Cadencement traitement cycle [40 ms]
		if(uc_CompteurCycle >= uc_CYCLE)
		{
			uc_CompteurCycle = 0;

			// gestion base de temps 1 seconde	
			uc_CompteurBase1S ++;
			if(uc_CompteurBase1S >= uc_1s_CADENCEMENT)
			{
				uc_CompteurBase1S = 0;
				b1_BT_1S = 1;			// flag seconde : à 1 chaque seconde pendant 1 cycle
			}

			vd_AnalyserEntrees();
			vd_TraitementApplicatif();
                        vd_Traitement_I2C();
			vd_PiloterSorties();

			b1_BT_1S = 0;				// flag seconde : à 1 chaque seconde pendant 1 cycle
			
			// xxx faire controle uc_FlagITTimer
			// xxx relance watchdog (+ init à faire au début)
                        /* xxx

        // Check WDT software flag to see if we need to clear the WDT. The
        // clearing of the WDT is disabled by this flag during I2C events to
        // increase reliablility of the slave I2C function. In the event that
        // a sequence on the I2C bus takes longer than expected, the WDT will
        // reset the device (and SSP module).
        if(!stat.wdtdis)
        CLRWDT();
                         * */

		}
	
	}
}

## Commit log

2025-12-08 docs: add PDF documentation (schematics, assembly, datasheet)
2025-12-21 docs: add hardware analysis documentation and schematics
2025-12-26 docs: add schematic previews to documentation
